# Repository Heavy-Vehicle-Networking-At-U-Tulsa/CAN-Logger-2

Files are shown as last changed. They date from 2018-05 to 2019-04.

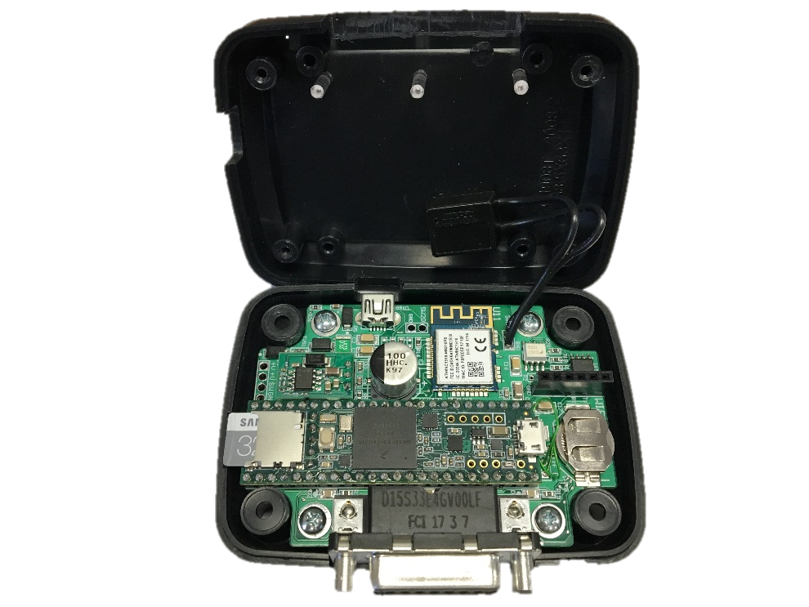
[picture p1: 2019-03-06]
docs/Picture of CAN Logger 2.png

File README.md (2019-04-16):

# CAN-Logger-2
Source code and documentation for the CAN Logger 2

## Purpose: 
Use as an educational tool to interface with CAN, including dual CAN channels, MCP2515 third CAN, Single Wire CAN, LIN, J1708, WIFI, LEDs, and pushed button

## Submodules
The CAN Logger 2 depends on the following libraries:
  * FlexCAN_Library forked from Collin80: https://github.com/Heavy-Vehicle-Networking-At-U-Tulsa/FlexCAN_Library
  * MCP_CAN_lib forked from Cory Fowler: https://github.com/Heavy-Vehicle-Networking-At-U-Tulsa/MCP_CAN_lib
  * Arduino's Wifi101 library: https://github.com/arduino-libraries/WiFi101
  
To use these submodules, you have to open a Git Bash command perform an update. Assuming Windows with Git installed:

```cd Documents/GitHub/CAN-Logger-2/``` (or equivalent directory for this repository.

```git submodule update --init```

### Installing Arduino Libraries
In Arduino 1.8.5, Click Sketch -> Include Library -> Add .Zip Library

Navigate to the submodule directory within this repository and select the name of the directory. A message should show up in Arduino saying "Library added to your libraries."

If there is an error in importing the libraries, you may need to remove exising libraries (see below).

#### Removing Existing Libraries 
Once the modules are updated, you need to make them available to your Arduino environment. Again, assuming Windows, open Git Bash.

```cd ~/Documents/Arduino/libraries```

``` rm -r FlexCAN_Library``` or other libraries.

You may also need to remove the pre-installed FlexCAN_Library:

```cd C:\Program Files (x86)\Arduino\hardware\teensy\avr\libraries```

``` rm -r FlexCAN_Library``` or other libraries.

## Usage
The following charts show the functionality of the CAN Logger 2 units. These charts are available as a pdf and include program flow and data structures.

[NMFTA TU CAN Logger 2 Diagrams](docs/NMFTA_TU_CAN_Logger_2%20Block%20Diagrams.pdf)

## Logger Device Test Programs
The test programs are in the `tests` directory

### `Test_LED_with_Button` 
Test code used to turn on three LEDs by pushing the button. The sketch makes use of the follwing defines based on the circuit design:

```
#define GREEN_LED_PIN 6
#define RED_LED_PIN 14
#define YELLOW_LED_PIN 5
#define button 21
```

### `Test_CAN0_and_CAN1`
Test codes used to send/receive CAN message periodically on both channels CAN0 and CAN1 using FLEX CAN library. 

This makes use of the following defines for the Silent Pins on the transceivers:
```
#define SILENT_0 39
#define SILENT_1 38
#define SILENT_2 37
```
Pull the silent pins low for transmission.

### `Test_MCP2515_Receive and Test_MCP2515_Send`
Test code used to send/receive CAN message periodically through third CAN channel using MCP library. 

## Utilities
There are a few utilities useful when using the CAN Logger 2.

### Flood the BUS with button
Test code to send messages with top priority messages at maximum speed to flood the bus as the button is pressed.

## WiFi
The CAN Logger 2 has a the ATWINC1500 Wifi module. By default, this module is disabled (i.e. not wired correctly.) If the wiring is fixed, then the Wifi can be used. 
Test codes used to wireless communicate through WiFi between the WiFi chip on the logger with one another. The WiFi 101 library can be accessed here: https://github.com/adafruit/Adafruit_WINC1500. To correctly use the WiFi chip on the Logger 2, SPI1 has to be selected by: Adafruit_WINC1500-master>src>bus_wrapper>source>nm_bus_wrapper_samd221.cpp, change line 54 to #define WINC1501_SPI SPI1.

## Acknowledgements 
This material is based upon work supported by the National Science Foundation under Grant No. 1715409.

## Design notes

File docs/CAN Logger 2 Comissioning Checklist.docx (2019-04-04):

Commissioning the CAN Logger 2

- Customer Name:_________________________________________________

Assembly:

- PCB board is screwed in the enclosure
- Push button is soldered in SW20 and attached to enclosure top half
- Jumper wire between R20 and RAW in P1 for optically isolated inputs
- Insert micro SD card
- Insert 3V coin battery

WiFi Enable / Disable (Circle one)

- WiFi enable - Jumper wire between Teensy pin 21 and WiFi chip RST pin
- WiFi disable - No jumper wire
- Screw enclosure top and bottom together
- Add D-Sub 15 to green 9-pin cable

Testing:

- Update firmware on Logger 2. Record the git commit hash: ________________

https://github.com/Heavy-Vehicle-Networking-At-U-Tulsa/CAN-Logger-2/tree/master/CAN_Logger_with_Autobaud_and_Requests

- Open Serial Monitor and Record the Logger 2 Date:_______________________
- Program and Label Enclosure Bottom with Serial number:__________________
- Enter the command FORMAT to clear the SD CARD.
- Enter the command COUNT to reset the file counter.
- Enter the command DF and record the free space on the SD Card: ___________
- Connect to live monitored CAN BUS (250k) with can0, can1, and can2 channels.
- Enter the command STREAM ON and see all three channels scroll in the first column.
- Double Click the Push Button and confirm 3 LEDs illuminate and a new file opens.
- Enter the Command LS A and confirm two files were created on the SD card.
- Press pushbutton once and confirm request messages are sent.
- Parse CAN Log to find ECM component ID. Record ID_______________________
- Unplug the CAN Logger USB first, then the DSUB cable while recording.
- Reconnect to live monitored CAN BUS (500k) with can0, can1, channels and J1708.
- Enter the command baudRate and confirm the new bitrates were recorded.
- Type the Command LS A and confirm the third file exists and after the power loss.
- Enter the command STREAM ON and confirm J1708 is not interfering can2
- Scan and record this checklist
- Insert the device, D-Sub cable and checklist in anti-static bag

Notes:

Selling and Shipping a Forensic Link Adapter with TruckCRYPT.docx Page 2 of 2

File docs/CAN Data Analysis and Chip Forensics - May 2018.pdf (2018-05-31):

Electronic Control Unit and CAN Data Analysis

Jeremy Daily, Ph.D., P.E.
jeremy-daily@utulsa.edu
Associate Professor of Mechanical Engineering

Overview

1. CAN Logger (version 2) Update
2. Network and Application Based CAN Capture
3. Chip Level Capture
4. Analysis, Decoding and Presenting the Data

Some contents were originally published in SAE 2015-01-1450

Logging Heavy Vehicle Network Traffic

■ Capture as much raw operational CAN data from heavy vehicles as possible. ■ Store Heavy Vehicle Network Messages on SD Card
■ Unique opportunity for a unique data set
■ Data is sanitized and stored by NMFTA
■ Implementation
■ CAN Logger V2
■ Faster
■ More Networks
■ Better Enclosure
■ Open Source
■ Functional Tool

NMFTA CAN Logger V2

■ Logging Interfaces
■ 3 – High Speed CAN
■ 1 – Single Wire CAN
■ 1 – LIN
■ 1 – J1708
■ External Connectivity
■ Vehicle Network Interface
■ Wi-Fi
■ USB
■ 180 MHz 32-bit ARM Cortex M4F ■ Button for marking data
■ Three LEDs

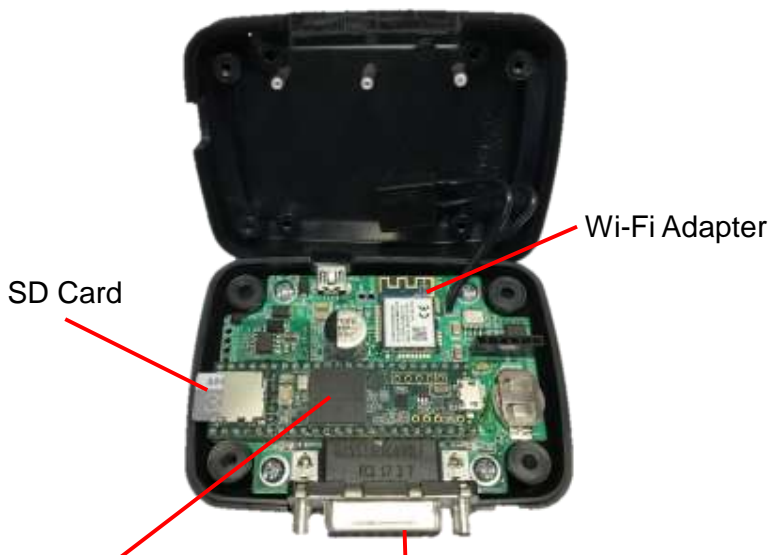
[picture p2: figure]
SD Card; Wi-Fi Adapter

Teensy 3.6 Arduino
Compatible
Development Board

Vehicle Network
Interface

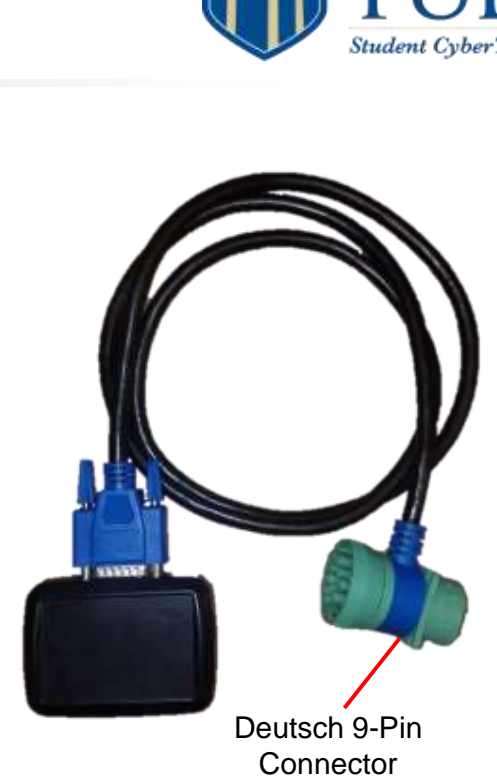
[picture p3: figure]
Deutsch 9-Pin Connector

Why is it Useful?

■ Vehicle Network Interface
■ D-sub 15 to Deutsch 9-Pin
■ Deutsch 9-Pin is a Heavy Vehicle Standard
■ Uses Diagnostic Port for Logging
■ Easy Data Collection of Heavy Vehicle Networks ■ Common Learning Platform
■ Statistical Differences Between
■ Normal Drive
■ Normal Drive with Attacks
■ 100% Open Source

Testing: Two at a Time

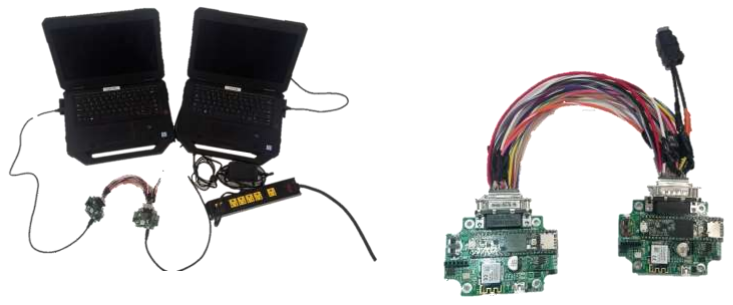
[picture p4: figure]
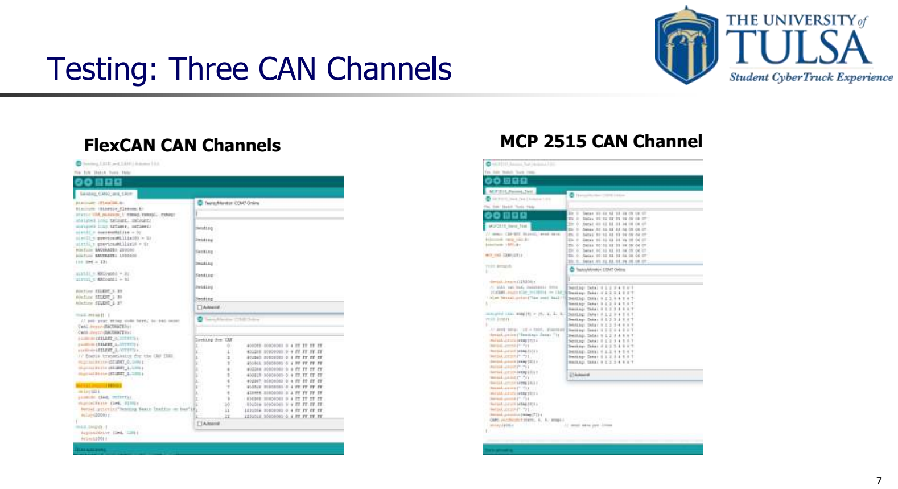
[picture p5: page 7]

Testing: Three CAN Channels

FlexCAN CAN Channels | MCP 2515 CAN Channel

Testing: Other Vehicle Networks

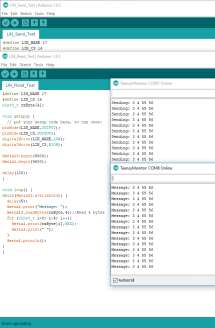
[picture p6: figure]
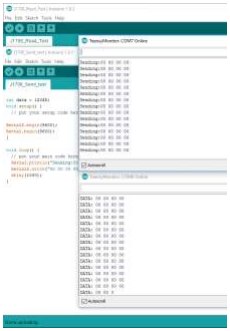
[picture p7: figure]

LIN | J1708

Testing: SD Card Writing Speed

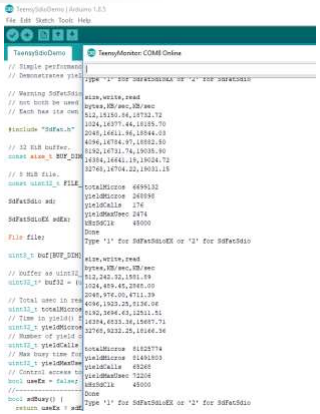
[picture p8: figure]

■ Write Time
■ 512 Bytes ≈ 240µS
■ Suitable For:
■ Full Bus Loads
■ Multiple CAN Channels
■ Logging Secondary Communications

LOGGING DATA WITH RP1210 APPLICATIONS

Alternative Method of Acquiring Data:

The TU-RP1210 Application

■ A Graphical User Interface to log, decode, and display data in with an open framework.
■ Python, Qt, and ctypes
■ Uses DLLs from RP1210 Vendors

`

J1939 Parameter Group Numbers

- Decoding
- Counting
- Timing

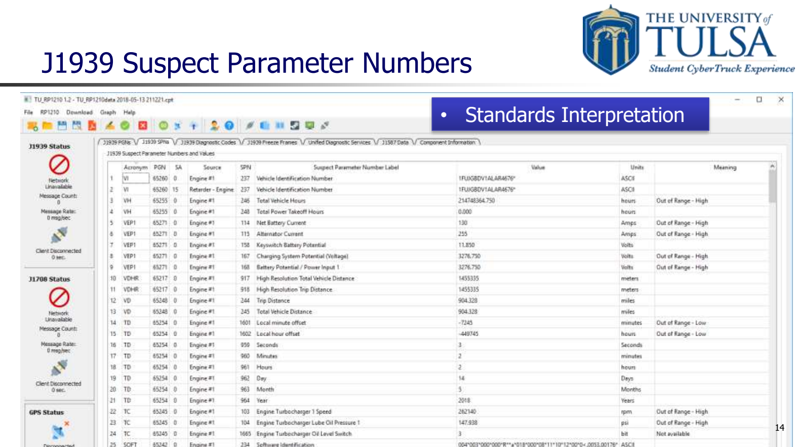
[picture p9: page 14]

J1939 Suspect Parameter Numbers

- Standards Interpretation

J1939 Diagnostic Codes (DM1 and DM2)

ISO-14229:
Unified Diagnostic Services (UDS)

Component Information Summary

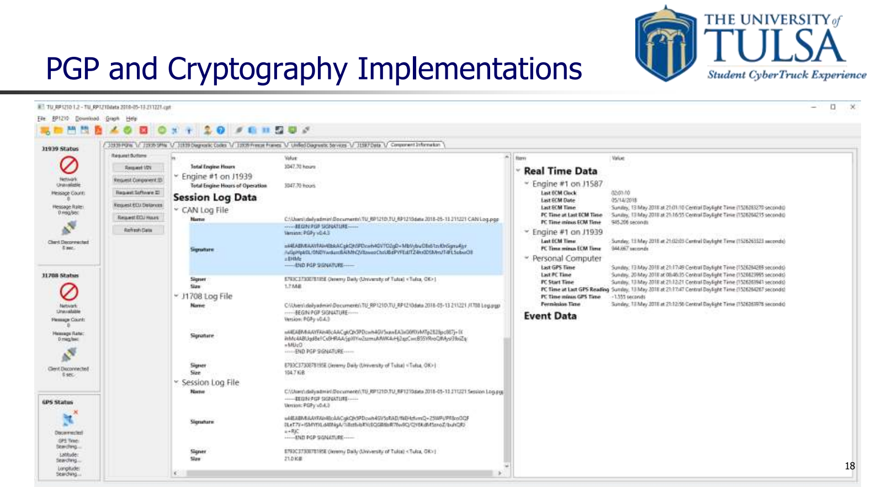
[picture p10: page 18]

PGP and Cryptography Implementations

Open Source Framework

■ Available on PyPi
■ Uses PyQT5
■ REST for Web Applications

■ Teaching Tool
■ RP1210 Function Validation ■ Data Analysis

Data Storage

■ JSON file for decoded data
■ CSV log files for Vehicle Networks
■ PDF Report generator using Reportlab
■ Pretty Good Privacy (PGP) implementation for file signing

CAN WE OBTAIN MEMORY
CONTENTS THOUGH JTAG PORTS?

Forget about the network…

A Journey Into Chip Forensics

Duy Van

Undergraduate in Mechanical Engineering duy-van@utulsa.edu

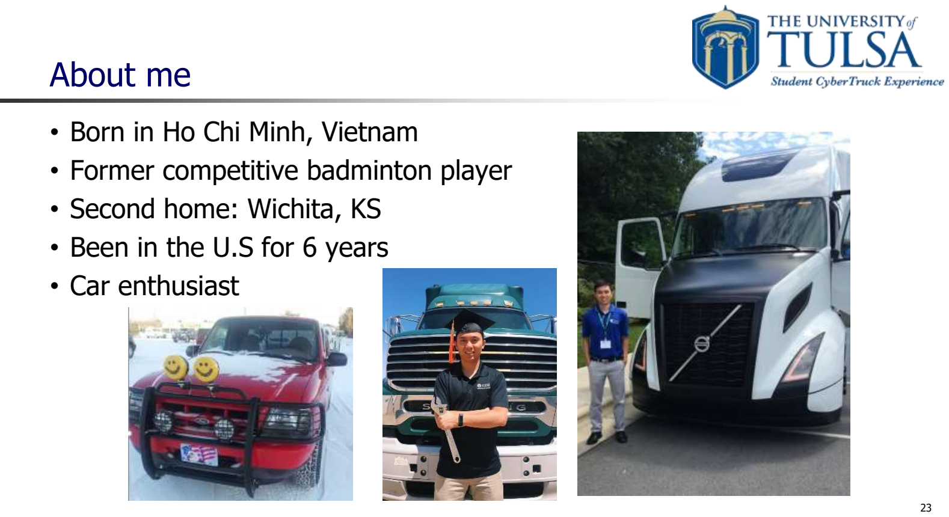
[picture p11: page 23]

About me

- Born in Ho Chi Minh, Vietnam
- Former competitive badminton player
- Second home: Wichita, KS
- Been in the U.S for 6 years
- Car enthusiast

Cyber Security Minor at UTULSA

Additional Courses

■ Intro to Cyber Security
■ Computer Forensics
■ Computer Security
■ Secure Electronic Commerce

Relevant Projects

■ Password cracking
■ Acquire and analyze computer’s hard drive
■ Writing AES encryption from scratch using C
■ Attack a virtual website with XSS, SQL injection, directory traversal, etc. and fix the vulnerabilities by changing source codes.

This is on top of a
Mechanical Engineering
degree…

Purposes and Procedures

■ Explore data patterns between RP1210 traffic logs and raw memory
■ Download Dataplate and Sudden Deceleration using Cummins PowerSpec
■ Collect raw data from FLASH and EEPROM through JTAG ■ Compare the data and decode raw binary

ECM Used

Cummins ECU CM870

DOWNLOADING DATA FROM
POWERSPEC

Tools

Inline 7
(Diagnostic Adapter)

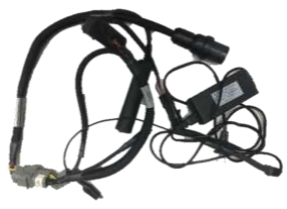
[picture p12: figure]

Connecting
Harness

Setup

Software

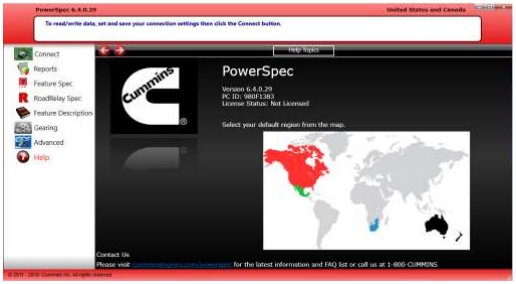
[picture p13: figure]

Cummins PowerSpec

Downloading Data

Dataplate | Sudden Deceleration

COLLECTING RAW DATA FROM K-TAG

Tool

AlienTech KTAG Master Kit from a European Chip Tuning shop

Software Interaction

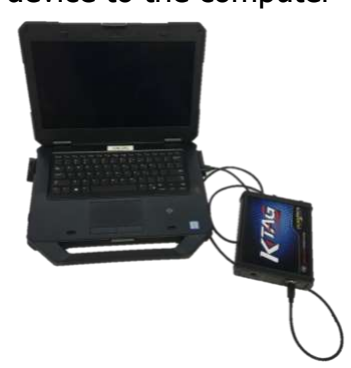
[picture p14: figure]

■ Connect KTAG device to the computer

Software Interaction

■ Run the K-Suite software from AlienTech

Software Interaction

■ Select purchased version (KTAG in this case)

Software Interaction

■ Purchased chip protocols will be in black font color and can be selected.
■ Vehicle types can also be selected if chip protocol is unknown at this moment.

Software Interaction

■ If chip protocol is known, choose the protocol

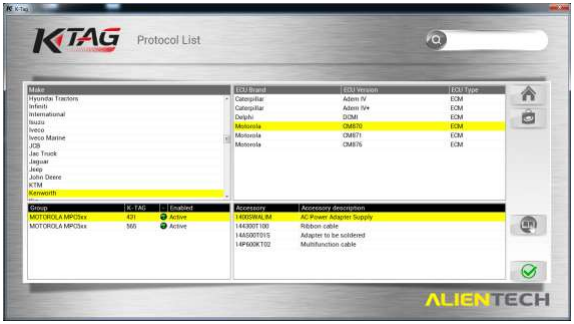
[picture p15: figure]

Software Interaction

■ If vehicle type is known, choose the vehicle

Software Interaction

■ Search option is also available

Software Interaction

■ After choosing the correct ECU, click on the book mark icon for wiring instruction

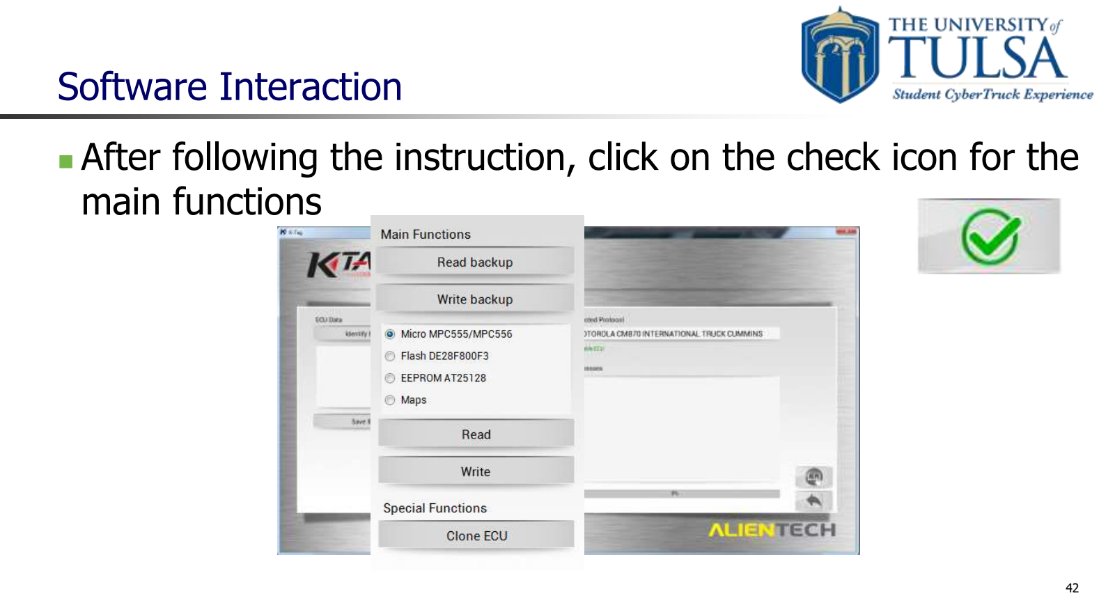
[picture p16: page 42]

Software Interaction

■ After following the instruction, click on the check icon for the main functions

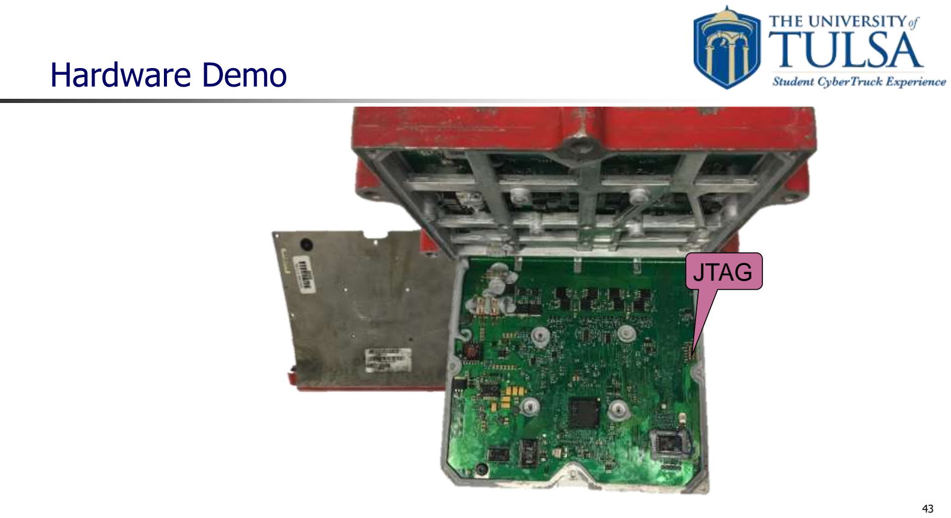
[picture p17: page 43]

Hardware Demo

JTAG

Hardware Interaction

■ Follow the instruction on the software, solder the port and

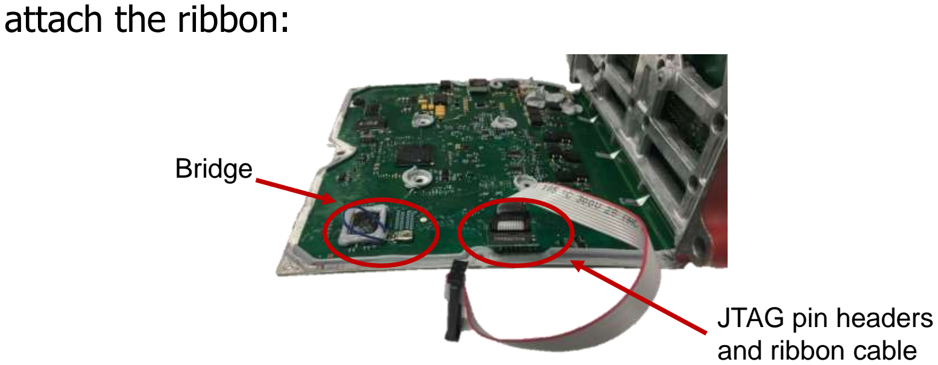
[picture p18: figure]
attach the ribbon:; Bridge; JTAG pin headers and ribbon cable

Hardware Interaction

■ Attach the D-sub cable to the ECU connector ■ Power
■ Ignition

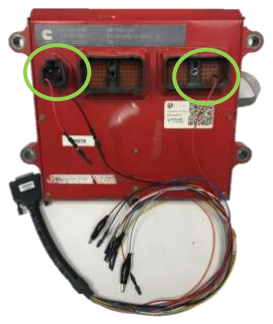
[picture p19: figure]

Setup

■ Connect the KTAG to the ECU and the computer

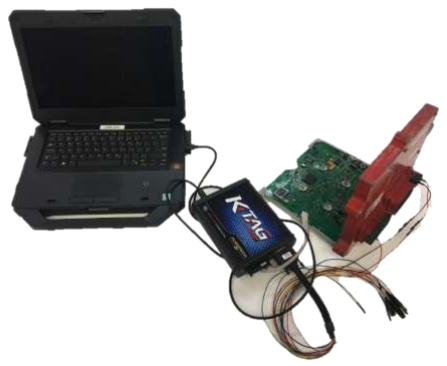
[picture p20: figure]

Retrieving Data

■ Select the desired function in the software ■ In this case, select Maps and Read function

Retrieving Data

■ Wait for the process to complete

Retrieving Data

■ Save the files separately

Data Analysis

■ Use Hexinator to open the output MPC file

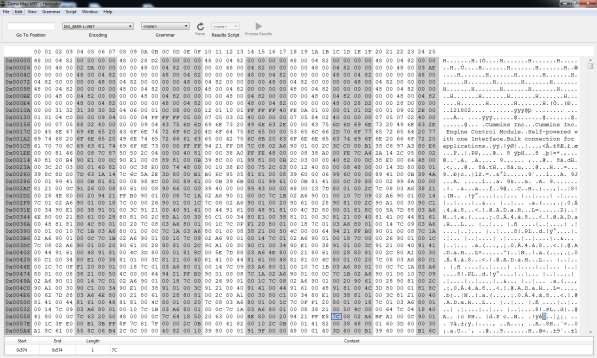
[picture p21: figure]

Data Analysis

■ Some meaningful strings are present indicating that the data is not encrypted

Data Analysis

■ Closer look between PowerSpec vs EEPROM

Data Analysis

■ For CM870, EEPROM carries data plate information via ASCII

Data Analysis

■ Flash file from KTAG

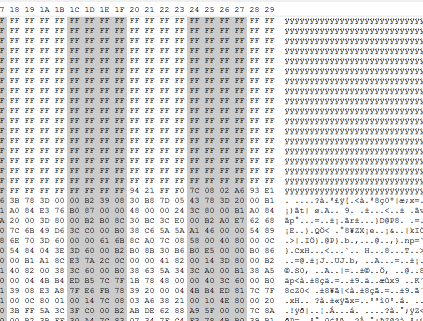
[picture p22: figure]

Data Analysis

■ Flash data can also be retrieved using individual chip reader

Xeltek Superpro 6000

Data Analysis ■ Flash chip data should

carry Sudden Decel
Information (vehicle
speed, engine RPM, etc.)
■ Not easy to find the data location

Data Analysis

One approach:
■ Vehicle speed for
Record 1 has 150 mph
for the first 60s

Data Analysis

■ Converting the actual vehicle speed into data format using J-1939-71

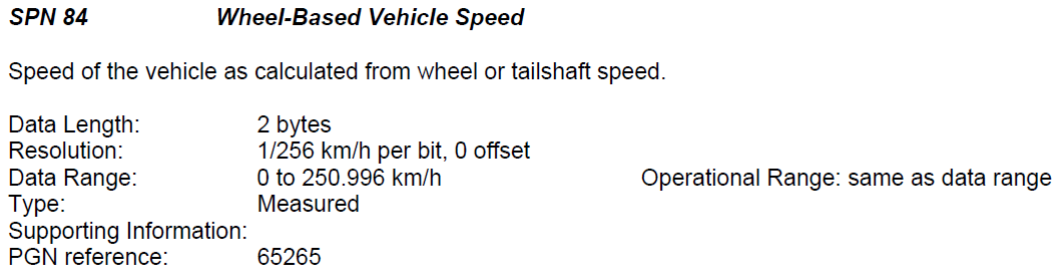
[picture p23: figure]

Data Analysis

■ Convert 150 mph to km/h: 241.4 km/h ■ Convert 241.4 km/h to bit:
241.4 km/h x 256 bit/km/h = 64798.4 bit ■ Convert 64798.4 to Hex: F1 66
■ Look for repeating F1 66 pattern in the FLASH memory

NO PATTERN! WHAT NOW?!

Data Analysis

■ Convert 150 mph to data format without converting to km/h ■ Convert 150 to bit:
150 *256 = 38,400
■ Convert 38,400 to Hex: 96 00

Data Analysis

■ WOOHOO! We got something

Data Analysis

■ But is it the vehicle speed log?
■ Tracing the speed along to compare with the report. The 2-byte is 12 bytes apart

Data Analysis

■ Convert 58 8A to actual vehicle speed number: ■ 58 8A to Decimal: 22,666
■ Convert 22,666 to actual number:
22,666 / 256 = 88.54 mph

Data Analysis

Data Analysis

■ What about engine RPM, load, throttle, etc.? ■ Take a look at 14-byte block in Record 2 data

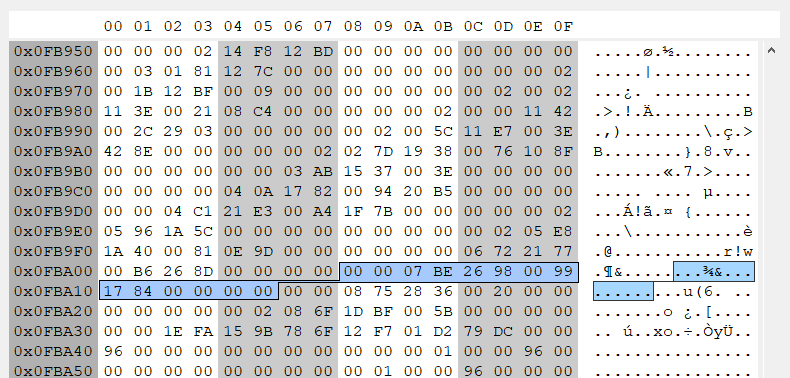
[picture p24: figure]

Data Analysis

Data Analysis

■ Comparing memory data with CAN traffic from PowerSpec

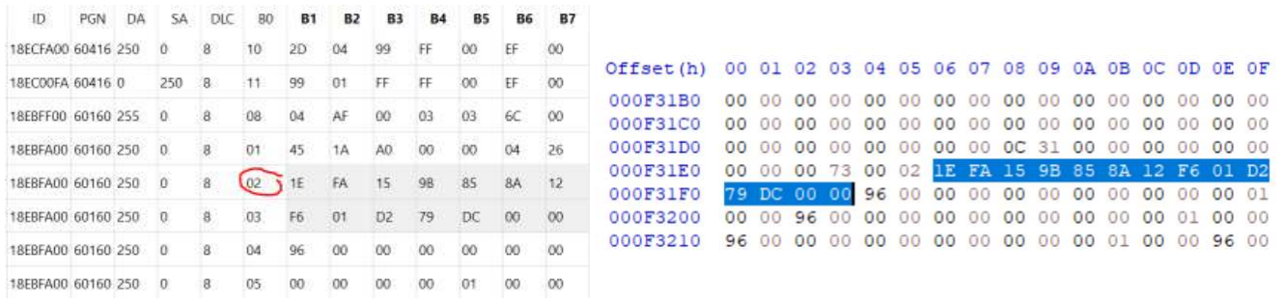
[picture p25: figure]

■ The results show CAN traffic delivers the exact data from
the memory with 7 bytes for every package | 68
CAN Traffic from PowerSpec | FLASH Memory

Next Steps

■ Write a script to parse through raw data to obtain sudden deceleration information
■ Explore the specific pattern to find the location of sudden decel for different ECUs
■ Write a Hexinator Grammar to automatically analyze binary data ■ Correlate network traffic with memory contents
■ Publish SAE papers
■ Maybe: patch memory to subvert normal functions

Additional Goals ■ Analyze multiple ECMs ■ Recover data from wrecked

ECMs
■ Recover data without setting fault codes
■ Virtual Chip Swap ■ Deep Dive: Build our own

KTAG tool

Thank you! | 70

Conclusions ■ Three ways of collecting data ■ CAN Data Loggers ■ Version 1 produced over 4000 hours ■ Version 2 has more tool-like features ■ RP1210 Application Logging ■ Fuzzing and Requesting ■ Eavesdropping ■ Memory Interrogation ■ Data Analysis ■ Counts and timing ■ Standards based meaning ■ Pattern matching

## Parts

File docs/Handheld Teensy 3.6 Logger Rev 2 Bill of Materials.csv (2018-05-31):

Comment | Description | Designator | Footprint | LibRef | Manufacturer 1 | Manufacturer Part Number 1 | Quantity | Supplier 1 | Supplier Order Qty 1 | Supplier Part Number 1
47 | ±1% 0.1W, 1/10W Chip Resistor 0603 (1608 Metric) Automotive AEC-Q200, High Voltage Thick Film | R5, R6, R24, R25 | 603 | Chip Resistor | Rohm | KTR03EZPF47R0 | 4 | Digi-Key | 4 | RHM47AYCT-ND
100k | ±1% 0.1W, 1/10W Chip Resistor 0603 (1608 Metric) Automotive AEC-Q200, High Voltage Thick Film | R8, R9, R11, R12, R13, R16, R17, R23, R26 | 603 | Chip Resistor | Rohm | KTR03EZPF1003 | 9 | Digi-Key | 9 | RHM100KAYCT-ND
4.7k | ±1% 0.1W, 1/10W Chip Resistor 0603 (1608 Metric) Automotive AEC-Q200, High Voltage Thick Film | R1, R4, R7, R10, R21, R22 | 603 | Chip Resistor | Rohm | KTR03EZPF4701 | 6 | Digi-Key | 6 | RHM4.7KAYCT-ND
1uf | 1µF ±20% 50V Ceramic Capacitor X5R 0603 (1608 Metric) | C10 | 603 | Cap | Murata | GRT188R61H105ME13D | 1 | Digi-Key | 1 | 490-12331-1-ND
10uF | 10µF ±20% 25V Ceramic Capacitor X5R 0603 (1608 Metric) | C4 | 603 | Cap | Murata | GRT188R61E106ME13D | 1 | Digi-Key | 1 | 490-12323-1-ND
10uF | 10µF ±20% 50V Ceramic Capacitor X5R 1206 (3216 Metric) | C5, C7 | 1206 | Cap | Murata | GRT31CR61H106ME01L | 2 | Digi-Key | 2 | 490-12457-1-ND
22uF | 22µF ±20% 25V Ceramic Capacitor X5R 1206 (3216 Metric) | C2, C12, C16, C17 | 1206 | Cap | Murata | GRT31CR61E226ME01L | 4 | Digi-Key | 4 | 490-12451-1-ND
330 | 330 Ohms ±1% 0.1W, 1/10W Chip Resistor 0603 (1608 Metric) Automotive AEC-Q200, High Voltage Thick Film | R2, R3, R18, R19, R20 | 603 | Chip Resistor | Rohm | KTR03EZPF3300 | 5 | Digi-Key | 5 | RHM330AYCT-ND
Varistor 26V | 34.5V 80A Varistor 1 Circuit Surface Mount 0805 (2012 Metric) | TVS1 | Transfeed | Transfeed | Kyocera AVX | V2AF126C600Y2EDP | 1 | Digi-Key | 1 | 478-10038-1-ND
OKI-78SR | 5V DC/DC Converter (7805 replacement) | U1 | OKI-78SR | 7805 | Murata | OKI-78SR-5/1.5-W36H-C | 1 | Digi-Key | 1 | 811-2692-ND
100uF | Aluminum Electrolytic Capacitors Radial, Can - SMD 5000 Hrs @ 105°C | C3 | Elec. Cap - G | Tantalum Cap_1 | Panasonic ECG | EEE-HC1H101P | 1 | Digi-Key | 1 | P19732CT-ND
ATECC508A | Authentication Chip IC Networking and Communications 8-SOIC | U15 | SOIC-8 | ATECC508A | Microchip / Atmel | ATECC508A-SSHDA-T | 1 | Digi-Key | 1 | ATECC508A-SSHDA-TCT-ND
MCP2515-E/ML | CAN Controller CAN 2.0 SPI Interface 20-QFN (4x4) | U14 | QFN-ML20_M | MCP2515-E/ML | Microchip | MCP2515-E/ML | 1 | Digi-Key | 1 | MCP2515-E/ML-ND
0.1uF | CAP CER 0.1UF 50V X7R 0603, CAP CER 0.1UF 50V 10% X7R 0603, CAP CER 0.1UF 50V 10% X7R 0603, CAP CER 0.1UF 50V X7R 0603, CAP CER 0.1UF 50V X7R 0603, CAP CER 0.1UF 50V 10% X7R 0603 | C1, C6, C8, C9, C11, C15 | 603 | Cap | Murata | GRM188R71H104KA93D | 6 | Digi-Key | 6 | 490-1519-1-ND
18pF | CAP CER 18PF 50V 5% NP0 0603 | C13, C14 | 603 | Cap | KEMET | C0603C180J5GAC-TU | 2 | Digi-Key | 2 | 399-1052-1-ND
Wifi | CONN HEADER FEMALE 6POS .1 GOLD" | WIFI | HDR1X6 | Header 6 | Sullins | PPPC061LFBN-RC | 1 | Digi-Key | 1 | S7039-ND
16MHz | CRYSTAL 16MHZ 18PF SMD | X1 | XTAL 2 pad | Crystal Oscillator | TXC | 7A-16.000MAAJ-T | 1 | Digi-Key | 1 | 887-1086-1-ND
ACURA107-HF | Diode Schottky 1000V 1A Surface Mount DO-214AC (SMA) | D3, D5 | SMA with A and K | Schottky Diode | Comchip | ACURA107-HF | 2 | Digi-Key | 1 | 641-1884-1-ND
SN75HVD08DR | IC RS485 TXRX 3/5V 8-SOIC | U4 | SOIC-SN8_N | SN75HVD12D (3.3v RS485) | Texas Instruments | SN75HVD08DR | 1 | Digi-Key | 1 | 296-37893-1-ND
74AHCT1G14 | IC SCHMIT-TRIGG INV GATE SOT353 | U3 | SOT-353 | 74AHCT1G14 Inverter | Diodes | 74AHCT1G14SE-7 | 1 | Digi-Key | 1 | 74AHCT1G14SE-7DICT-ND
ADG1634BCPZ-REEL7 | IC SWITCH QUAD SPDT 20LFCSP | U6 | ADI-CP-20-4_N | ADG1634BCPZ-REEL7 | Analog Devices | ADG1634BCPZ-REEL7 | 1 | Digi-Key | 1 | ADG1634BCPZ-REEL7CT-ND
Green | LED GREEN DIFFUSED 0805 SMD | D1 | 0805 Polarized | LED - SMD | Osram Opto | LGR971-KN-1-0-20-R18 | 1 | Digi-Key | 1 | 475-1410-1-ND
Red | LED RED DIFFUSED 0805 SMD | D2 | 0805 Polarized | LED - SMD | Osram Opto | LSR976-NR-1 | 1 | Digi-Key | 1 | 475-1278-1-ND
Yellow | LED YELLOW DIFFUSED 0805 SMD | D4 | 0805 Polarized | LED - SMD | Osram Opto | Q62702P5177 | 1 | Digi-Key | 1 | 475-2560-1-ND
MCP2003A-E/SN | LIN J2602 Transceiver, 8-Pin SOIC, Extended Temperature, Tape and Reel | U7 | SOIC-SN8_N | MCP2003AT-E/SN | Microchip | MCP2003A-E/SN | 1 | Digi-Key | 1 | MCP2003A-E/SN-ND
NCP1117LPST33 | Linear Voltage Regulator IC Positive Fixed Output 3.3V 1A SOT-223 | U13 | SOT-223 | NCP1117 2.5V | ON Semiconductor | NCP1117LPST33T3G | 1 | Digi-Key | 1 | NCP1117LPST33T3GOSCT-ND
CR1225 | Lithium Battery Non-Rechargeable (Primary) 3V Coin, 12.5mm | Batt1 | Battery Clip - CR1225 | CR2032 Battery Holder | Linx | BAT-HLD-012-SMT | 1 | Digi-Key | 1 | BAT-HLD-012-SMT-ND
MCP2558 | Microchip CAN FD Transceiver with Silent Mode | U5, U8, U9 | TDFN | MCP2558FD | Microchip |  | 3 | Arrow | 3 | MCP2558FDT-H/MNY
MOCD207R2M | Optoisolator Transistor Output 2500Vrms 2 Channel 8-SO Tall | U12 | SOIC-8 | Optoisolator - Dual | Fairchild Semiconductor | MOCD207R2-M | 1 | Digi-Key | 1 | MOCD207R2MCT-ND
PTC RESTTBLE 0.75A | PTC RESTTBLE 0.75A 33V CHIP 1812 | PTC1 | 1812 | PTC | Bel | 0ZCG0075BF2B | 1 | Digi-Key | 1 | 507-1765-1-ND
Vehicle Interface Cable Connector | Receptacle Assembly, 15 Position, Right Angle | J1 | DSUB1.385-2H15 | D Connector 15 | Amphenol FCI | D15S33E4GV00LF | 1 | Digi-Key | 1 | 609-1498-ND
NCV7356D1R2G | Single Wire CAN Transceiver, 5 to 27 V, 8-Pin SOIC, Pb-Free, Tube | U2 | ONSC-SOIC-8-751-07_V | NCV7356D1G | ON Semiconductor | NCV7356D1R2G | 1 | Digi-Key | 1 | NCV7356D1R2GOSCT-ND
ATML-ATWINC1500-MR210PA-28 | SMARTCONNECT ATWINC1500B-MU-T MO | U11 | ATML-ATWINC1500-MR210PA-28_V | ATML-ATWINC1500-MR210PA-28 | Microchip | ATWINC1510-MR210PB1140 | 1 | Digi-Key | 1 | ATWINC1510-MR210PB1140-ND
SMA6J | TVS DIODE 20VWM 36.8VC SMA | Z1 | SMA | Zener - Bidirectional | MCC | SMA6J24CA-TP | 1 | Digi-Key | 1 | SMA6J24CA-TPMSCT-ND
UX60SC-MB-5S8 | USB - mini B USB 2.0 Receptacle Connector 5 Position Surface Mount, Right Angle; Through Hole | USB1 | USB Mini UX60S | USB-Rugged | Hirose | UX60SC-MB-5S8 | 1 | Digi-Key | 1 | H11589CT-ND

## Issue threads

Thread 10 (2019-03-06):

Serial Command

duyvan1995, 2019-03-06:
Command start with brand_name on line 1031 just closes the current file.
Command HEX and BIN print the latest log file but are they supposed to save them on PC? If yes then location to save? @jeremy-daily

jeremydaily, 2019-03-31:
These commands are to stream the data in the specified format for storage with another computer.

Closed 2019-03-31.

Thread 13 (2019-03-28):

CAN1 is not working when plug in

duyvan1995, 2019-03-28:
CAN1 only works if the Logger stops the current file after plugging in and starts a new log file

jeremydaily, 2019-03-31:
Is this an autobaud issue? Can you duplicate this issue and provide more description of the setup @duyvan1995?

duyvan1995, 2019-03-31:
The issue is resolved with the latest code

duyvan1995, 2019-04-07:
Just saw the same issue: if the is rebooted (was off then plugged in the BUS to start recording), the streaming and recording will only see channel 0 until I typed "stop" in the serial command and the channel 1 started showing up. Double click the button won't fix the issue

duyvan1995, 2019-04-07:
The issue occurs when plugging in the the ECM and SSS2 only, I plugged in a TruckCape and do a cangen on can1 and the issue is gone. Not sure what happened

jeremy-daily, 2019-04-08:
Can we close this again?

Closed 2019-04-08.

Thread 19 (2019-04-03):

Request component ID

duyvan1995, 2019-04-03:
Does not see request messages sent from the device

duyvan1995, 2019-04-04:
Fixed with new source code

Closed 2019-04-04.

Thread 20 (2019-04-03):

Listen Only Mode

duyvan1995, 2019-04-03:
Device does not act as a node even if listen only mode is set to false

jeremy-daily, 2019-04-08:
Was this was fixed with the updated flexcan library?

duyvan1995, 2019-04-08:
No, still did not see messages generated from a single CAN Logger, need to plug in a SSS2 to see those messages

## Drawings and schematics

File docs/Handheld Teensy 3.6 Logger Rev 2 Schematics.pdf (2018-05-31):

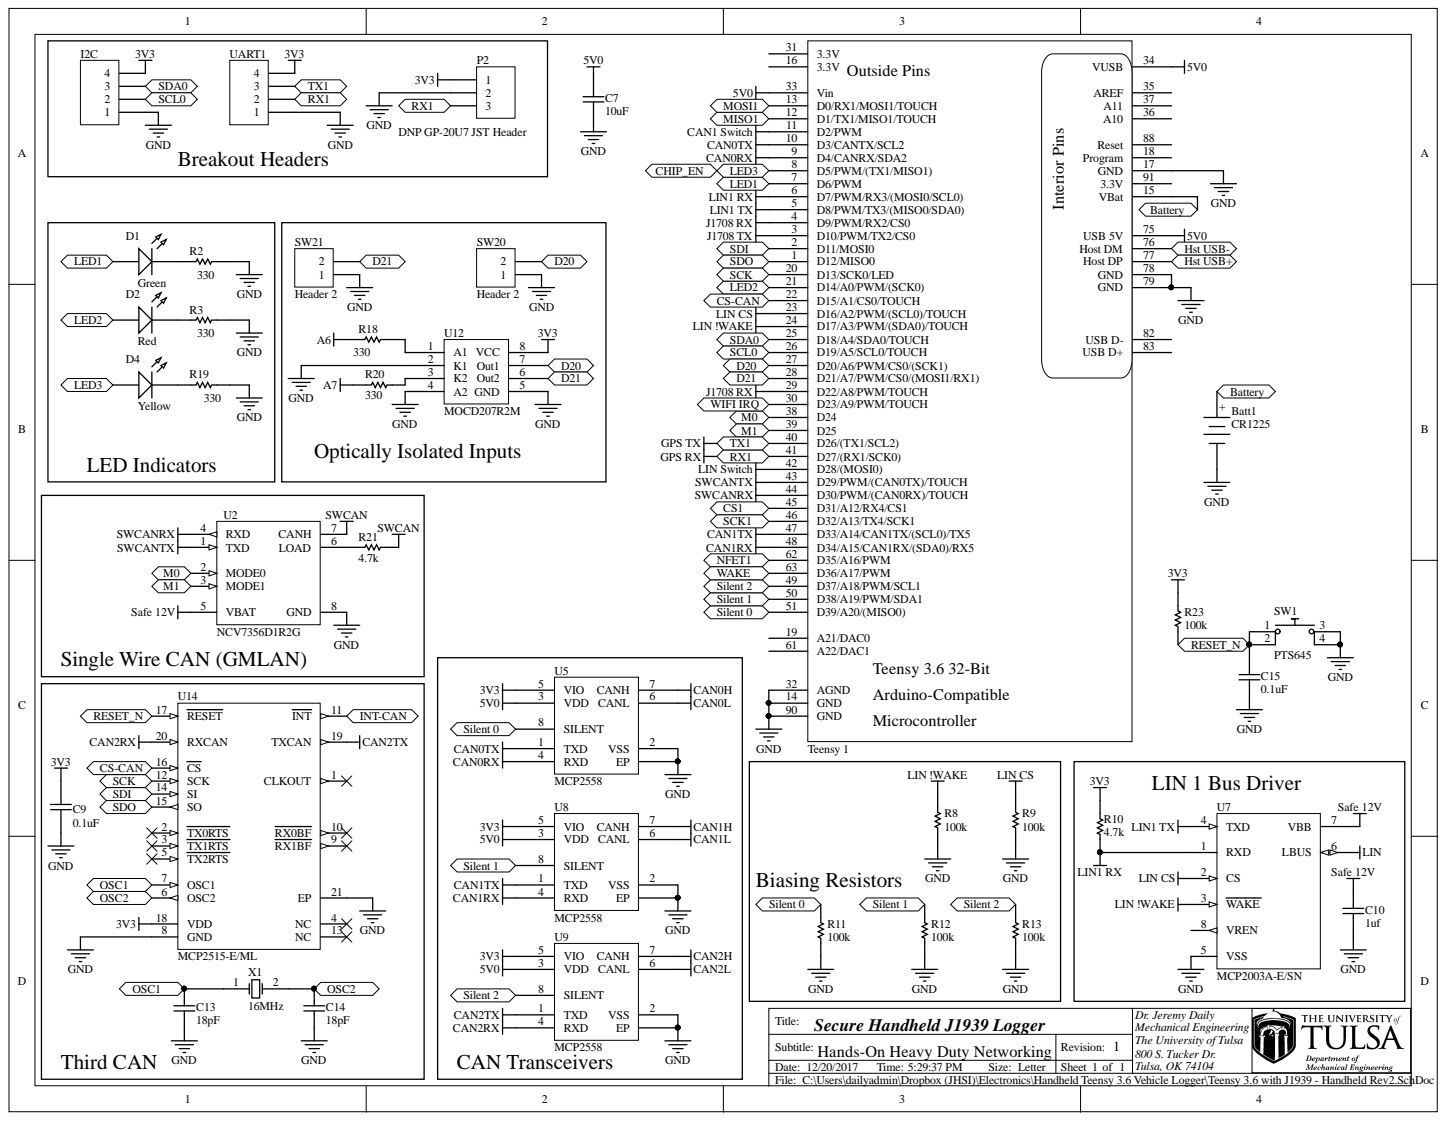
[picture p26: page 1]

GND
DNP GP-20U7 JST Header

Single Wire CAN (GMLAN)

Title: Secure Handheld J1939 Logger | Dr. Jeremy Daily Mechanical Engineering The University of Tulsa 800 S. Tucker Dr. Tulsa, OK 74104

Hands-On Heavy Duty Networking Subtitle: | 1 Revision:

Date: 12/20/2017 Time: 5:29:37 PM Size: Letter | Sheet of

C:\Users\dailyadmin\Dropbox (JHSI)\Electronics\Handheld Teensy 3.6 Vehicle Logger\Teensy 3.6 with J1939 - Handheld Rev2.SchDoc

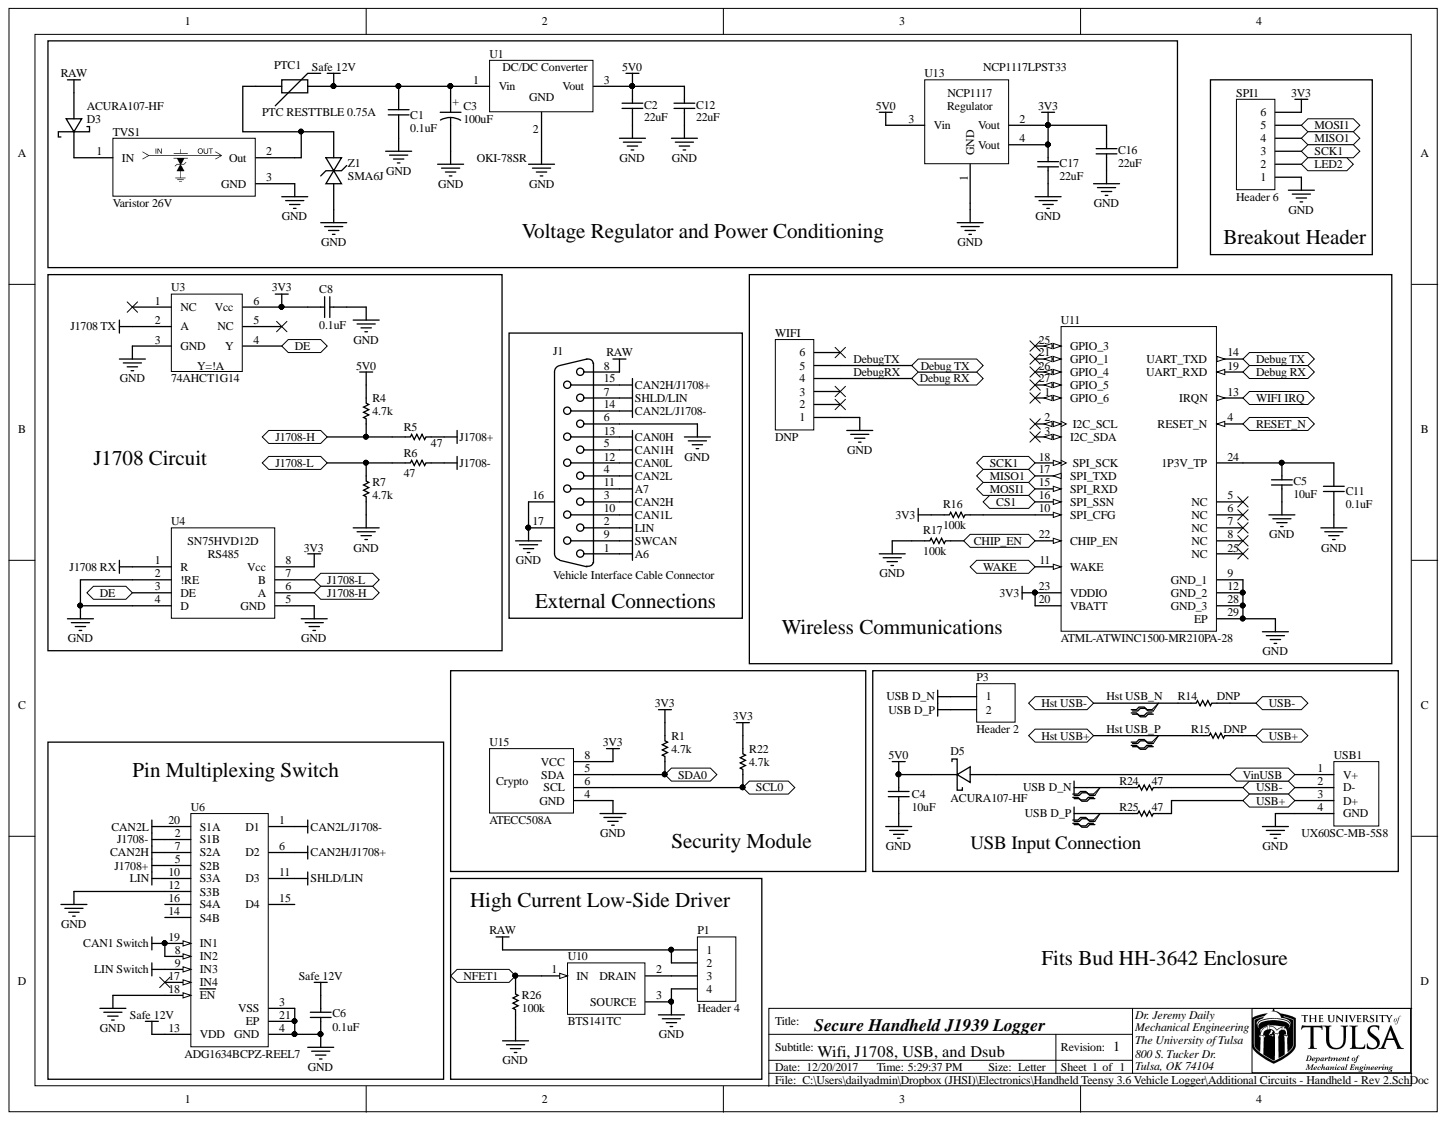
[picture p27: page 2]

Voltage Regulator and Power Conditioning

Vehicle Interface Cable Connector
External Connections

High Current Low-Side Driver

U10
IN 1 DRAIN | 2

Fits Bud HH-3642 Enclosure

Dr. Jeremy Daily
Mechanical Engineering
The University of Tulsa
800 S. Tucker Dr.
Tulsa, OK 74104

Subtitle:
C:\Users\dailyadmin\Dropbox (JHSI)\Electronics\Handheld Teensy 3.6 Vehicle Logger\Additional Circuits - Handheld - Rev 2.SchDoc

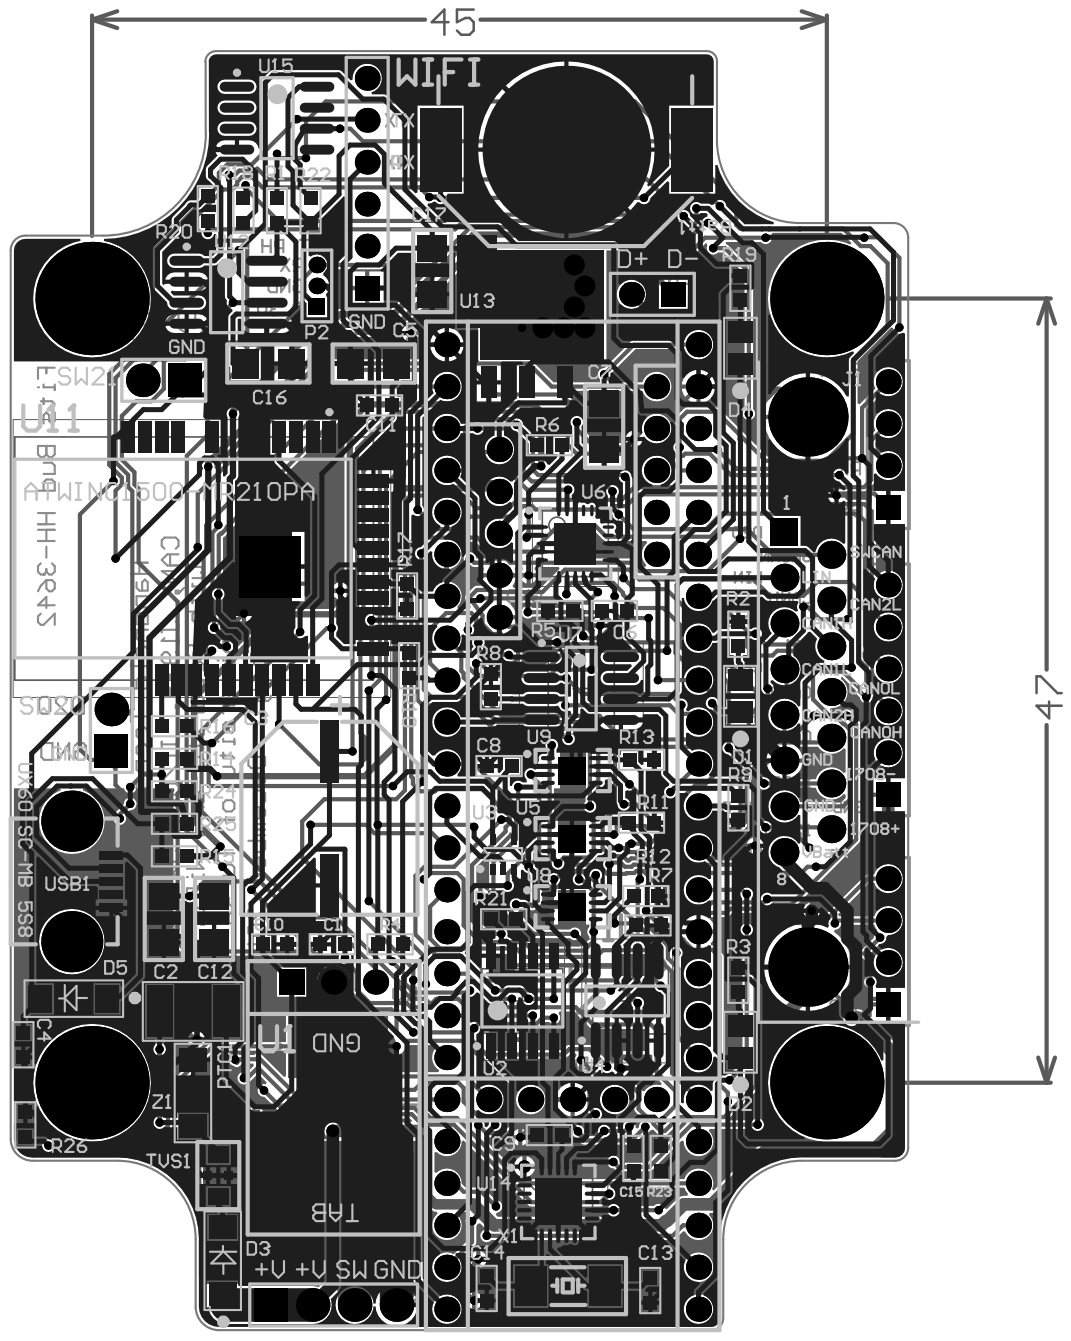
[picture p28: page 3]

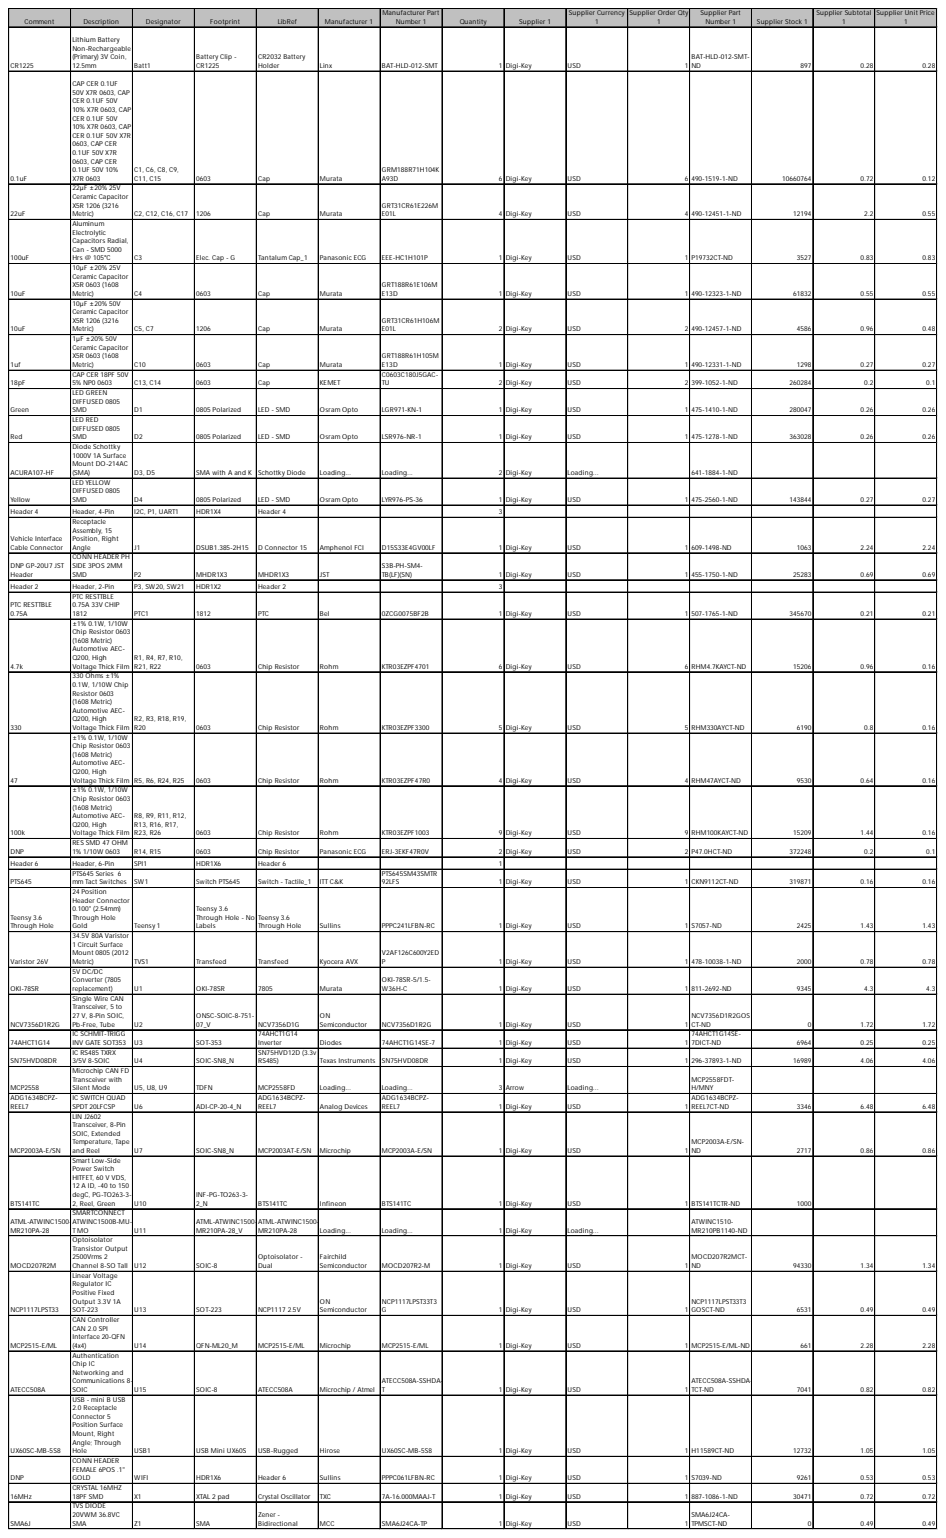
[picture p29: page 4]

Comment | Description | Designator | Footprint | LibRef | Manufacturer 1 | Manufacturer Part Number 1 | Quantity | Supplier 1 | Supplier Currency | Supplier Order Qty | Supplier Part Number 1 | Supplier Stock 1 | Supplier Subtotal | Supplier Unit Price

CR1225 | Lithium Battery Non-Rechargeable (Primary) 3V Coin, 12.5mm | Batt1 | Battery Clip -CR1225 | CR2032 Battery Holder | Linx | BAT-HLD-012-SMT | 1 | Digi-Key | USD | | BAT-HLD-012-SMT-1 ND | 897 | 0.28 | 0.28

0.1uF | CAP CER 0.1UF 50V X7R 0603, CAP CER 0.1UF 50V 10% X7R 0603, CAP CER 0.1UF 50V 10% X7R 0603, CAP CER 0.1UF 50V X7R 0603, CAP CER 0.1UF 50V X7R 0603, CAP CER 0.1UF 50V 10% X7R 0603 | C1, C6, C8, C9, C11, C15 | 0603 | Cap | Murata | GRM188R71H104K A93D | 6 | Digi-Key | USD | | 6 490-1519-1-ND | 10660764 | 0.72 | 0.12

22uF | 22µF ±20% 25V Ceramic Capacitor X5R 1206 (3216 Metric) | C2, C12, C16, C17 | 1206 | Cap | Murata | GRT31CR61E226M E01L | 4 | Digi-Key | USD | | 4 490-12451-1-ND | 12194 | 2.2 | 0.55

100uF | Aluminum Electrolytic Capacitors Radial, Can - SMD 5000 Hrs @ 105°C | C3 | Elec. Cap - G | Tantalum Cap_1 | Panasonic ECG | EEE-HC1H101P | 1 | Digi-Key | USD | | 1 P19732CT-ND | 3527 | 0.83 | 0.83

10uF | 10µF ±20% 25V Ceramic Capacitor X5R 0603 (1608 Metric) | C4 | 0603 | Cap | Murata | GRT188R61E106M E13D | 1 | Digi-Key | USD | | 1 490-12323-1-ND | 61832 | 0.55 | 0.55

10uF | 10µF ±20% 50V Ceramic Capacitor X5R 1206 (3216 Metric) | C5, C7 | 1206 | Cap | Murata | GRT31CR61H106M E01L | 2 | Digi-Key | USD | | 2 490-12457-1-ND | 4586 | 0.96 | 0.48

1uf | 1µF ±20% 50V Ceramic Capacitor X5R 0603 (1608 Metric) | C10 | 0603 | Cap | Murata | GRT188R61H105M E13D | 1 | Digi-Key | USD | | 1 490-12331-1-ND | 1298 | 0.27 | 0.27

18pF | CAP CER 18PF 50V 5% NP0 0603 | C13, C14 | 0603 | Cap | KEMET | C0603C180J5GAC-TU | 2 | Digi-Key | USD | | 2 399-1052-1-ND | 260284 | 0.2 | 0.1

Green | LED GREEN DIFFUSED 0805 SMD | D1 | 0805 Polarized | LED - SMD | Osram Opto | LGR971-KN-1 | 1 | Digi-Key | USD | | 1 475-1410-1-ND | 280047 | 0.26 | 0.26

Red | LED RED DIFFUSED 0805 SMD | D2 | 0805 Polarized | LED - SMD | Osram Opto | LSR976-NR-1 | 1 | Digi-Key | USD | | 1 475-1278-1-ND | 363028 | 0.26 | 0.26

ACURA107-HF | Diode Schottky 1000V 1A Surface Mount DO-214AC (SMA) | D3, D5 | SMA with A and K | Schottky Diode | Loading... | Loading... | 2 | Digi-Key | Loading... | | 641-1884-1-ND

Yellow | LED YELLOW DIFFUSED 0805 SMD | D4 | 0805 Polarized | LED - SMD | Osram Opto | LYR976-PS-36 | 1 | Digi-Key | USD | | 1 475-2560-1-ND | 143844 | 0.27 | 0.27

Header 4 | Header, 4-Pin | I2C, P1, UART1 | HDR1X4 | Header 4 | | | 3
Vehicle Interface Cable Connector | Receptacle Assembly, 15 Position, Right Angle | J1 | DSUB1.385-2H15 | D Connector 15 | Amphenol FCI | D15S33E4GV00LF | 1 | Digi-Key | USD | | 1 609-1498-ND | 1063 | 2.24 | 2.24

DNP GP-20U7 JST Header | CONN HEADER PH SIDE 3POS 2MM SMD | P2 | MHDR1X3 | MHDR1X3 | JST | S3B-PH-SM4-TB(LF)(SN) | 1 | Digi-Key | USD | | 1 455-1750-1-ND | 25283 | 0.69 | 0.69

Header 2 | Header, 2-Pin | P3, SW20, SW21 | HDR1X2 | Header 2 | | | 3
PTC RESTTBLE 0.75A | PTC RESTTBLE 0.75A 33V CHIP 1812 | PTC1 | 1812 | PTC | Bel | 0ZCG0075BF2B | 1 | Digi-Key | USD | | 1 507-1765-1-ND | 345670 | 0.21 | 0.21

4.7k | ±1% 0.1W, 1/10W Chip Resistor 0603 (1608 Metric) Automotive AEC-Q200, High Voltage Thick Film | R1, R4, R7, R10, R21, R22 | 0603 | Chip Resistor | Rohm | KTR03EZPF4701 | 6 | Digi-Key | USD | | 6 RHM4.7KAYCT-ND | 15206 | 0.96 | 0.16
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

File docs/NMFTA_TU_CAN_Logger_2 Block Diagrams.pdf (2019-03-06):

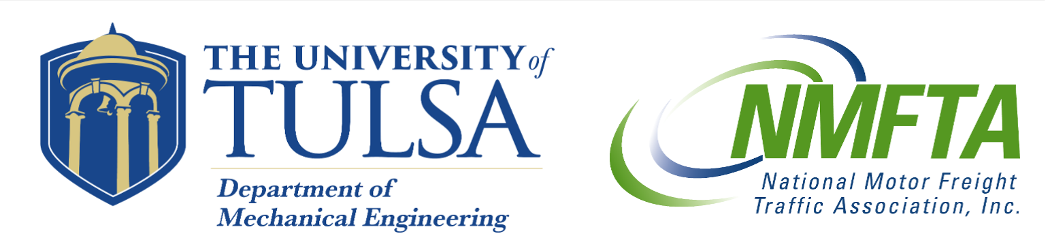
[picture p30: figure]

# National Science Foundation

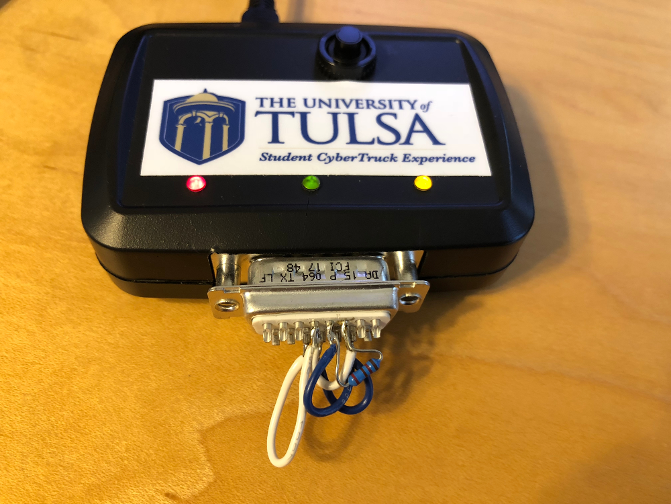
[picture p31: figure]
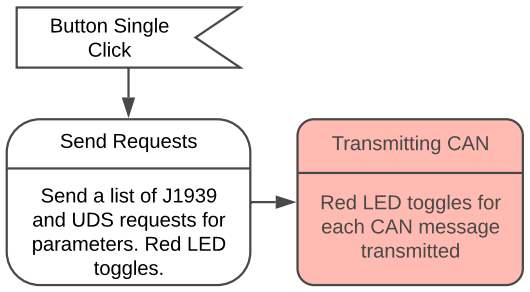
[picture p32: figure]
Transmitting CAN; Red LED toggles for each CAN message transmitted; Button Single Click; Send Requests; Send a list of J1939 and UDS requests for parameters. Red LED toggles.
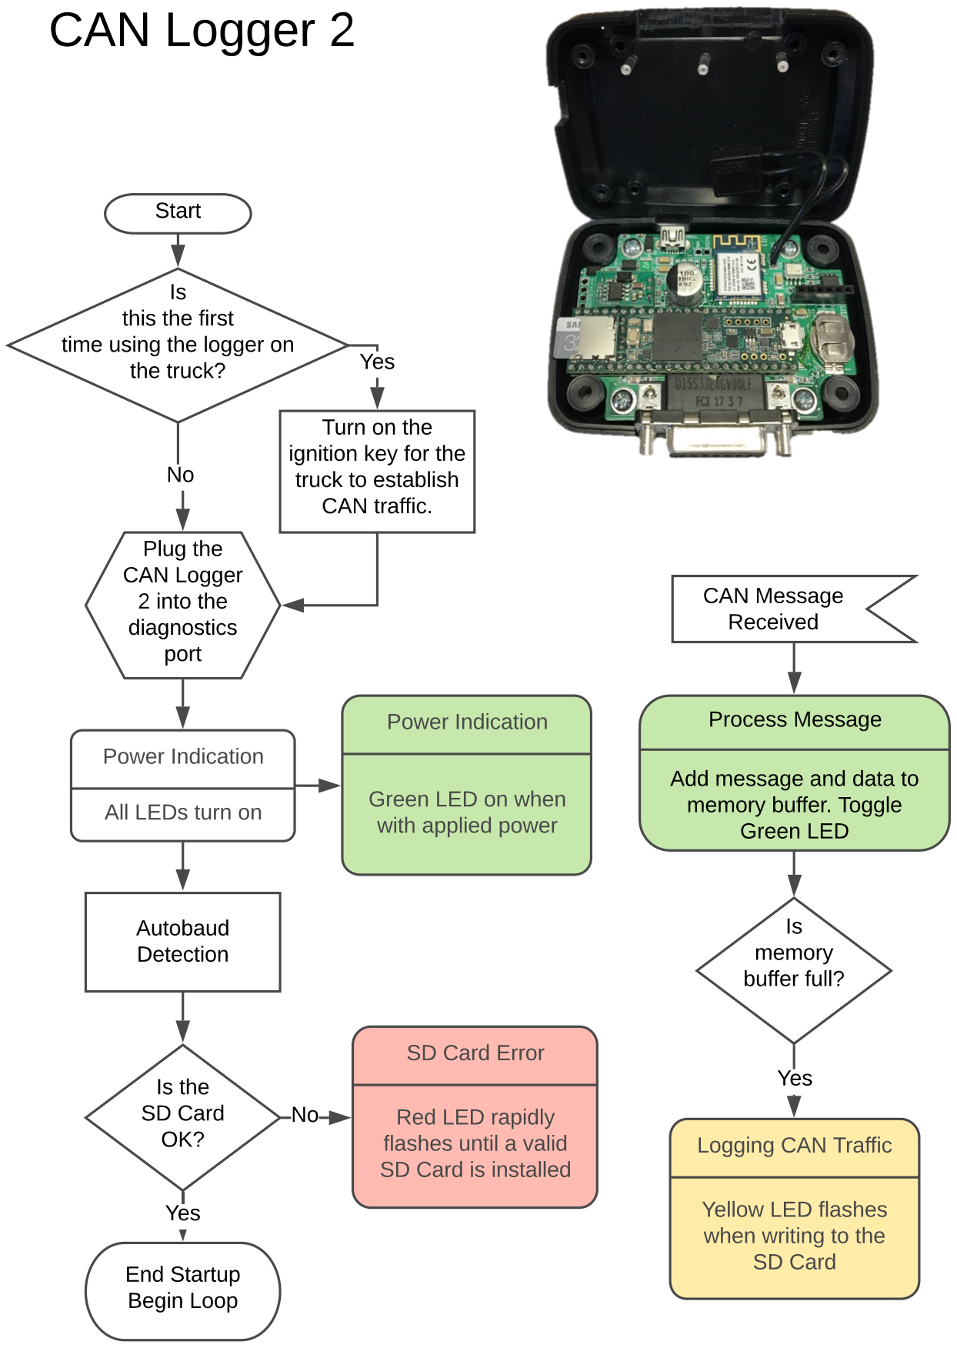
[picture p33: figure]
CAN Logger 2; Power Indication; All LEDs turn on; Start; Is this the first time using the logger on; the truck?; Yes; Turn on the ignition key for the truck to establish CAN traffic.; Plug the CAN Logger; 2 into the diagnostics port; Logging CAN Traffic; Yellow LED flashes when writing to the SD Card; Autobaud Detection; End Startup Begin Loop; CAN Message Received; Process Message; Green LED on when with applied power; Is the SD Card OK?; SD Card Error; Red LED rapidly flashes until a valid SD Card is installed; Is memory; buffer full?

This material is based upon work supported by the National Science Foundation under Grant No. 1715409, titled

### "Detecting and Reconstructing Network Anomalies and Intrusions in Heavy Duty Vehicles"

NMFTA/TU CAN Logger 2 | User Guide | Last Modified by: Jeremy Daily on 6-Mar-2019 | Page 1 of 6

Detecting Error Frames

Red LED flickers when
CAN bus error messages are detected.

Cable is unplugged
(power lost)

Shutdown

Close Current File

Add message and data to memory buffer. Toggle Green LED Button Double Click

Close File

Closes the file and
opens a new one in with the next

sequence number

CAN Bus Error

Process Error Message

Flag a message in the memory buffer by setting the 30th bit. Follow SocketCAN's error message handleing.

LEDs Off

All LEDs turn off while new file is

created

Autobaud
Detection

End Startup
Begin Loop

Continue
Loop

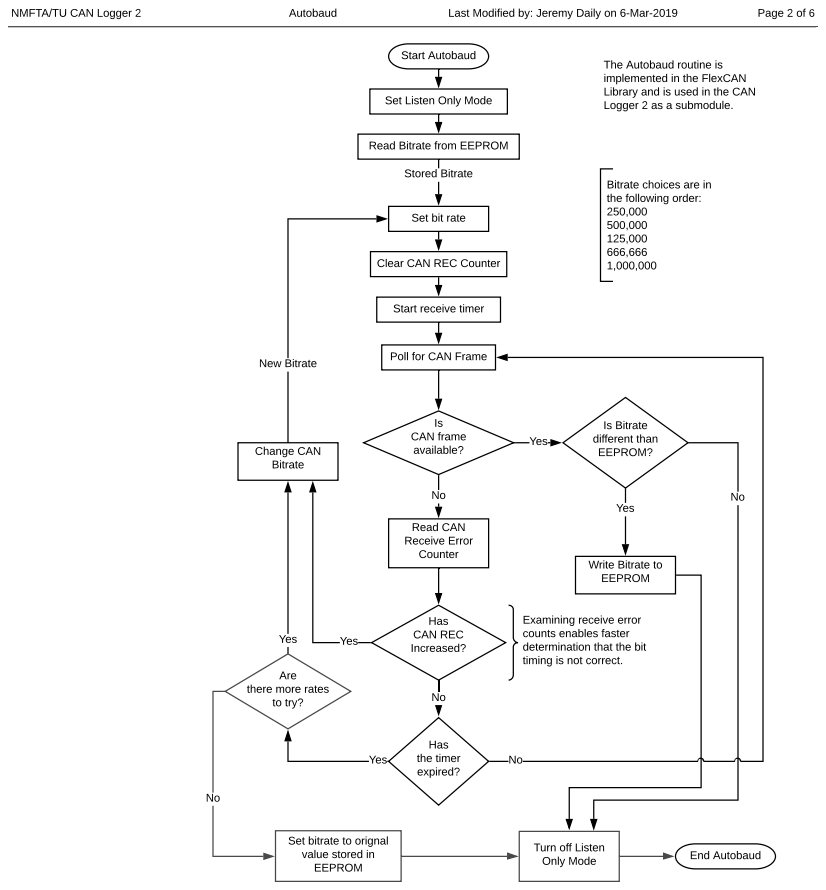
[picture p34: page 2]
Start Autobaud; Stored Bitrate; available?; Has CAN REC Increased?; Change CAN Bitrate; Yes; Is Bitrate different than EEPROM?; Has the timer expired?; New Bitrate; Bitrate choices are in the following order: 250,000 500,000 125,000 666,666 1,000,000; NMFTA/TU CAN Logger 2; Autobaud; Last Modified by: Jeremy Daily on 6-Mar-2019; Page 2 of 6; End Autobaud

The Autobaud routine is
implemented in the FlexCAN
Library and is used in the CAN
Logger 2 as a submodule.

Set Listen Only Mode

Read Bitrate from EEPROM

Set bit rate

Clear CAN REC Counter

Start receive timer

Poll for CAN Frame

Is CAN frame

Read CAN
Receive Error Counter

Write Bitrate to
EEPROM

Examining receive error
counts enables faster
determination that the bit
timing is not correct.

Are
there more rates
to try?

Set bitrate to orignal
value stored in

Turn off Listen Only Mode

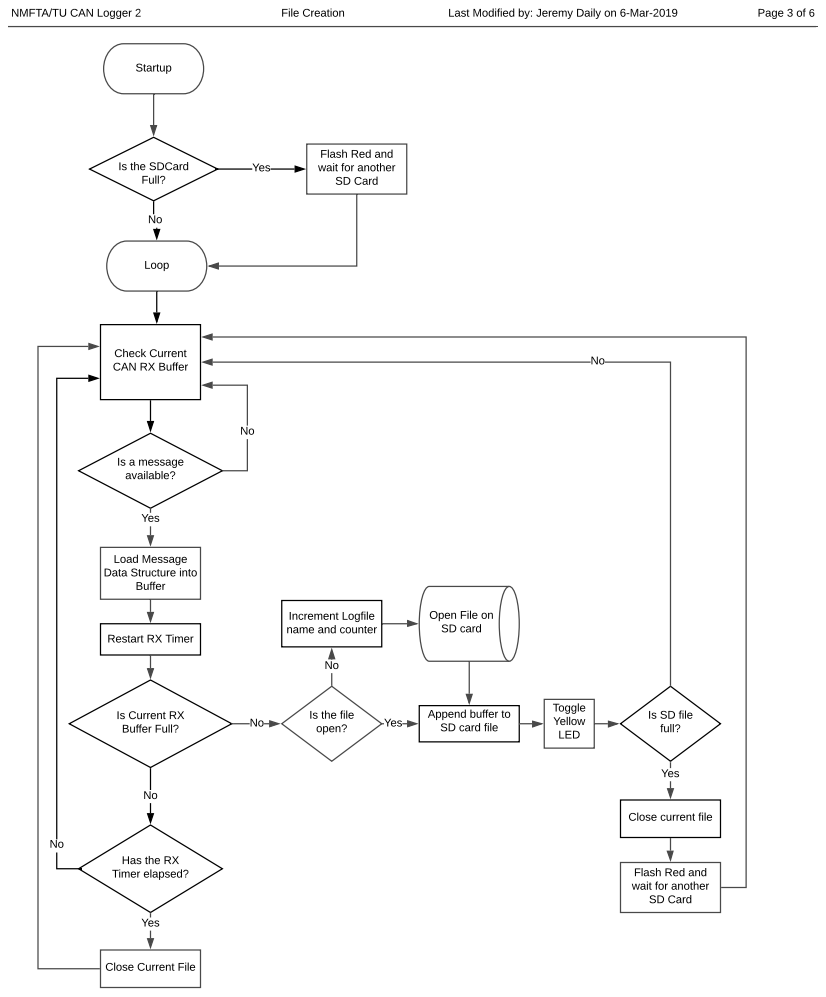
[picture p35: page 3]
Is a message available?; Yes; NMFTA/TU CAN Logger 2; File Creation; Last Modified by: Jeremy Daily on 6-Mar-2019; Page 3 of 6; open?; Toggle Yellow LED; SD Card; Startup; Loop; Buffer

Flash Red and wait for another

Is the SDCard
Full?

Check Current
CAN RX Buffer

Load Message Data Structure into

Increment Logfile
name and counter

Open File on
SD card

Restart RX Timer

Is Current RX
Buffer Full?

Is the file

Append buffer to
SD card file

Is SD file
full?

Close current file

Has the RX
Timer elapsed?

Flash Red and
wait for another
SD Card

Close Current File

Serial Commands | Interrupts

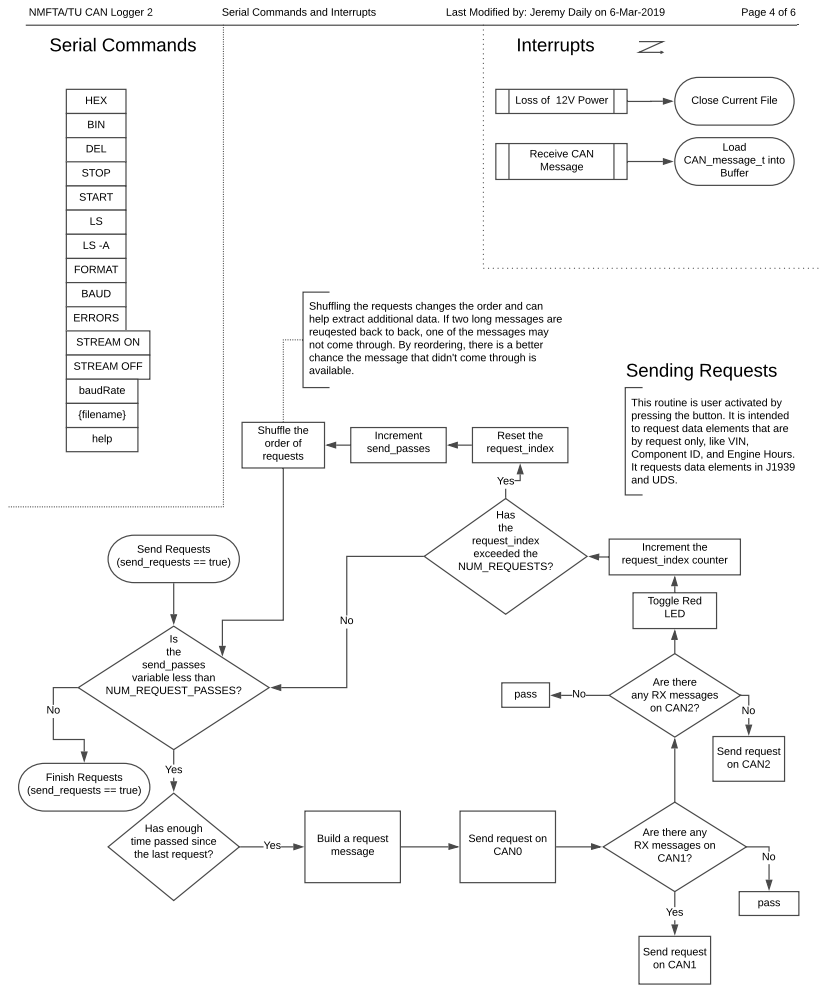
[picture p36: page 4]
NMFTA/TU CAN Logger 2; Serial Commands and Interrupts; Last Modified by: Jeremy Daily on 6-Mar-2019; Page 4 of 6; HEX; BIN; DEL; STOP; START; FORMAT; BAUD; ERRORS; STREAM ON; STREAM OFF; baudRate; {filename}; Loss of 12V Power; Close Current File; Receive CAN Message; Load CAN_message_t into Buffer; help; Send Requests (send_requests == true); Is the send_passes variable less than NUM_REQUEST_PASSES?; Yes; Build a request message; Send request on CAN1; pass; Send request on CAN2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

Shuffling the requests changes the order and can
help extract additional data. If two long messages are
reuqested back to back, one of the messages may
not come through. By reordering, there is a better
chance the message that didn't come through is

This routine is user activated by
pressing the button. It is intended
to request data elements that are
by request only, like VIN, Component ID, and Engine Hours.

It requests data elements in J1939
and UDS.

Are there
any RX messages
on CAN2?

Has enough
time passed since
the last request?

Send request on CAN0

Are there any
RX messages on CAN1?
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

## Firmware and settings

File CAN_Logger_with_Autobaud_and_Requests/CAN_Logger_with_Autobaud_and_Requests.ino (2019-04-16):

/*
 * NMFTA CAN Logger 2 Project
 * 
 * Arduino Sketch for the CAN Logger 2 to record up to 3 CAN channels using
 * a Teensy 3.6. See https://github.com/Heavy-Vehicle-Networking-At-U-Tulsa/CAN-Logger-2
 * for more details.
 * 
 * Written By Dr. Jeremy S. Daily
 * The University of Tulsa
 * Department of Mechanical Engineering
 * 
 * 18 Nov 2018
 * 
 * Released under the MIT License
 *
 * Copyright (c) 2018        Jeremy S. Daily
 *
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
 * 
 * This program logs data to a binary file.  
 * 
 * Samples are logged at regular intervals.  The maximum logging rate
 * depends on the quality of your SD card. 
 * 
 * Much of this sketch was inspired by the examples from https://github.com/greiman/SdFs
 * 
 * The program makes use of the SdFs library
 * 
 */


//included libraries 
#include <SdFs.h>
#include <mcp_can.h>
#include <FlexCAN.h>
#include <OneButton.h>
#include <TimeLib.h>
#include <EEPROM.h>
#include <error.h>
#include <FastCRC.h>

//Get access to a hardware based CRC32 
FastCRC32 CRC32;

// EEPROM memory addresses for creating file names
// The Address 0 and 1 are used for baud rates by the fork FlexCAN submodule -- see src/FlexCAN.h
#define EEPROM_DEVICE_ID_ADDR  4 // 5, 6, 7=00
#define EEPROM_FILE_ID_ADDR    8 // 9, 10, 11 ==00
#define EEPROM_BRAND_NAME_ADDR 12 //13 and 14 ==00

// Setup a limit to turn off the CAN controller after this many messages.
#define ERROR_COUNT_LIMIT 5000

// setup the length for a serial command buffer to control the logger 2.
#define COMMAND_BUFFER_LEN 20 
char command_buffer[COMMAND_BUFFER_LEN];

// Set up the SD Card object
SdFs sd;

#define SD_CONFIG SdioConfig(FIFO_SDIO)

// Create a file object
FsFile binFile;
FsFile baudFile;

String directory_listing;

// All CAN messages are received in the FlexCAN structure
CAN_message_t rxmsg,txmsg;

// Define CAN TXRX Transmission Silent pins
// See the CAN Logger 2 Schematic for the source pins
#define SILENT_0   39
#define SILENT_1   38
#define SILENT_2   37
#define CAN_SWITCH 2
#define BUTTON_PIN 20
#define POWER_PIN  21

// Use the button for multiple inputs: click, doubleclick, and long click.
OneButton button(BUTTON_PIN, true);

String commandString;

/*  code to process time sync messages from the serial port   */
char timeString[100];

// define a counter to reset after each second is counted.
elapsedMicros microsecondsPerSecond;

// Get a uniqueName for the Logger File
char logger_name[4];
bool file_open;
char current_file_name[13];
char prefix[5];
char file_name_prefix[6];
char brand_name[3];
  
  
// Setup the MCP2515 controller
// See the CAN Logger 2 Schematic for the source pins
#define CS_CAN 15
MCP_CAN Can2(CS_CAN); 
//variables for the CAN Message
uint32_t rxId;
uint8_t len;
uint8_t rxBuf[8];
uint8_t ext_flag;

#define FAST_BLINK_TIME 50 //milliseconds
#define SLOW_BLINK_TIME 500 //milliseconds

//Setup LEDs
#define GREEN_LED 6
#define RED_LED 14
#define YELLOW_LED 5

boolean GREEN_LED_state;
boolean RED_LED_state;
boolean YELLOW_LED_state;

elapsedMillis GREEN_LED_Slow_Timer;
elapsedMillis RED_LED_Slow_Timer;
elapsedMillis YELLOW_LED_Slow_Timer;

elapsedMillis GREEN_LED_Fast_Timer;
elapsedMillis RED_LED_Fast_Timer;
elapsedMillis YELLOW_LED_Fast_Timer;

boolean GREEN_LED_slow_blink_state;
boolean RED_LED_slow_blink_state;
boolean YELLOW_LED_slow_blink_state;

boolean GREEN_LED_fast_blink_state;
boolean RED_LED_fast_blink_state;
boolean YELLOW_LED_fast_blink_state;


// Setup a counter to keep track of the filename
char current_file[4];

// Keep track of the CAN Channel (0, 1, or 2, where 2 is MCP CAN)
uint8_t current_channel;


// There are 2 data buffers that get switched. We need to know which one
// we are using and where we are in the buffer.
#define CAN_FRAME_SIZE 25
#define MAX_MESSAGES 19
#define BUFFER_POSITION_LIMIT (CAN_FRAME_SIZE * MAX_MESSAGES)
#define BUFFER_SIZE 512
uint8_t data_buffer[BUFFER_SIZE];
uint16_t current_position;

//Counter and timer to keep track of transmitted messages
#define TX_MESSAGE_TIME 2 //milliseconds
uint32_t TXCount0 = 0;
uint32_t TXCount1 = 0;
uint32_t TXCount2 = 0;
elapsedMillis TXTimer0;
elapsedMillis TXTimer1;
elapsedMillis TXTimer2;

// To use a button to send requests, we need to track it.
#define NUM_REQUEST_PASSES 3
#define REQUEST_TIMING 250 //milliseconds
elapsedMillis send_request_timer;
elapsedMillis send_iso_request_timer;
boolean send_requests;
boolean send_iso_requests;
uint16_t request_index;
uint16_t iso_request_index;
uint8_t send_passes;
uint8_t send_iso_passes;

#define NUM_REQUESTS 27
uint16_t request_pgn[NUM_REQUESTS] = {
  65261, // Cruise Control/Vehicle Speed Setup
  65214, // Electronic Engine Controller 4
  65259, // Component Identification
  65242, // Software Identification
  65244, // Idle Operation
  65260, // Vehicle Identification
  65255, // Vehicle Hours
  65253, // Engine Hours, Revolutions
  65257, // Fuel Consumption (Liquid)
  65256, // Vehicle Direction/Speed
  65254, // Time/Date
  65211, // Trip Fan Information
  65210, // Trip Distance Information
  65209, // Trip Fuel Information (Liquid)
  65207, // Engine Speed/Load Factor Information
  65206, // Trip Vehicle Speed/Cruise Distance Information
  65205, // Trip Shutdown Information
  65204, // Trip Time Information 1
  65200, // Trip Time Information 2
  65250, // Transmission Configuration
  65203, // Fuel Information (Liquid)
  65201, // ECU History
  65168, // Engine Torque History
  64981, // Electronic Engine Controller 5
  64978, // ECU Performance
  64965, // ECU Identification Information
  65165  // Vehicle Electrical Power #2
};

#define NUM_ISO_REQUESTS 9
uint16_t iso_request[NUM_ISO_REQUESTS] = {
  0xF195, //System Supplier ECU Software Version Number
  0xF190, //Vehicle Identfication Number
  0xF193, //System Supplier ECU Hardware Version Number
  0xF18C, //ECU Serial Number
  0xF180, //Boot Software Identfication
  0xF181, //Application Software Identfication
  0xF186, //Active Diagnostic Session
  0xF192, //System Supplier ECU Hardware Number
  0xF197, //System Name or Engine Type
};
    
//Create a counter and timer to keep track of received message traffic
#define RX_TIME_OUT 1000 //milliseconds
elapsedMillis RXTimer;
uint32_t RXCount0 = 0;
uint32_t RXCount1 = 0;
uint32_t RXCount2 = 0;
elapsedMillis lastCAN0messageTimer;
elapsedMillis lastCAN1messageTimer;
elapsedMillis lastCAN2messageTimer;
uint32_t ErrorCount0 = 0;
uint32_t ErrorCount1 = 0;
uint32_t ErrorCount2 = 0;

// Should we stream the CAN frame to the serial port? Serial 
// can't keep up with heavy CAN bus loads, so this is default to false.
bool stream = false;

// Track the state of the user's desire to log. This can toggle based 
// on user input.
bool recording = true;

/*
 * The load_buffer() function maps the received CAN message into
 * the positions in the buffer to store. Each buffer is 512 bytes.
 * 20 CAN messages can fit in the buffer since they are 25 bytes long.
 * Note: an additional channel byte was added when comparing to the 
 * NMFTA CAN Logger 1 files. 
 * 
 * Use this function to understand how the the binary file format was created.
 * When reading the binary, be sure to read it in 512 byte chunks.
 */
void load_buffer(){
  // reset the timer
  RXTimer = 0;

  //Toggle the LED
  GREEN_LED_state = !GREEN_LED_state;
  digitalWrite(GREEN_LED, GREEN_LED_state);
    
  data_buffer[current_position] = current_channel;
  current_position += 1;
  
  time_t timeStamp = now();
  memcpy(&data_buffer[current_position], &timeStamp, 4);
  current_position += 4;
  
  memcpy(&data_buffer[current_position], &rxmsg.micros, 4);
  current_position += 4;

  memcpy(&data_buffer[current_position], &rxmsg.id, 4);
  current_position += 4;

  // Store the message length as the most significant byte and use the 
  // lower 24 bits to store the microsecond counter for each second.
  uint32_t DLC = (rxmsg.len << 24) | (0x00FFFFFF & uint32_t(microsecondsPerSecond));
  memcpy(&data_buffer[current_position], &DLC, 4);
  current_position += 4;

  memcpy(&data_buffer[current_position], &rxmsg.buf, 8); 
  current_position += 8;

  if ((rxmsg.id & CAN_ERR_FLAG) == CAN_ERR_FLAG){
    RED_LED_state = !RED_LED_state;
    digitalWrite(RED_LED, RED_LED_state);  
  }
  
  // Check the current position and see if the buffer needs to be written 
  // to the SD card.
  check_buffer();
}

void check_buffer(){
  //Check to see if there is anymore room in the buffer
  if (current_position >= BUFFER_POSITION_LIMIT){ //max number of messages
    //Create a file if it is not open yet
    if (!file_open) {
      open_binFile();
      Serial.print("Opened File ");
      Serial.println(current_file_name);
    }
  
    uint32_t start_micros = micros();
    
    // Write the beginning of each line in the 512 byte block
    sprintf(prefix,"CAN2");
    memcpy(&data_buffer[0], &prefix, 4);
    current_position = 4;
    
    memcpy(&data_buffer[479], &RXCount0, 4);
    memcpy(&data_buffer[483], &RXCount1, 4);
    memcpy(&data_buffer[487], &RXCount2, 4);
    
    data_buffer[491] = Can0.readREC();
    data_buffer[492] = Can1.readREC();
    data_buffer[493] = uint8_t(Can2.errorCountRX());
    
    data_buffer[494] = Can0.readTEC();
    data_buffer[495] = Can1.readTEC();
    data_buffer[496] = uint8_t(Can2.errorCountTX());
    
    // Write the filename to each line in the 512 byte block
    memcpy(&data_buffer[497], &current_file_name, 8);
  
    uint32_t checksum = CRC32.crc32(data_buffer, 508);
    memcpy(&data_buffer[508], &checksum, 4);
    
    if (BUFFER_SIZE != binFile.write(data_buffer, BUFFER_SIZE)) {
      Serial.println("write failed");
      sdErrorFlash(); 
    }

    //Reset the record
    memset(&data_buffer,0xFF,512);
    
    //Record write times for the previous frame, since the existing frame was just written
    uint32_t elapsed_micros = micros() - start_micros;
    memcpy(&data_buffer[505], &elapsed_micros, 3);
 
    //Toggle LED to show SD card writing
    YELLOW_LED_state = !YELLOW_LED_state;
    digitalWrite(YELLOW_LED,YELLOW_LED_state);
  }
}

void print_hex(){
  turn_recording_off();
  turn_streaming_off();
  char line[512];
  if (!binFile.isOpen()) close_binFile();
  if (sd.exists(current_file_name)){
    binFile.open(current_file_name, O_READ);
    while (binFile.read(line, sizeof(line)) > 0) {
      for (uint16_t i = 0; i < sizeof(line); i++){
        char disp[4];
        sprintf(disp,"%02X ",line[i]);
        Serial.print(disp);
      }  
      Serial.println();
    }
    binFile.close();
    setup();
  }
  else
  {
    Serial.println("Current file does not exist");
  }
}

void delete_file(char delete_file_name[]){
  if (!binFile.isOpen()) close_binFile();
  // Remove any existing file.
  if (sd.exists(delete_file_name)) {
    sd.remove(delete_file_name); 
  }
  else
  {
    Serial.println("Current file does not exist");
  }
}

void stream_binary(char stream_file_name[]){
  turn_streaming_off();
  turn_recording_off();
  char line[512];
  if (!binFile.isOpen()) close_binFile();
  if (sd.exists(stream_file_name)){
    binFile.open(stream_file_name, O_READ);
    while (binFile.read(line, sizeof(line)) > 0) 
    {
      for (uint16_t i = 0; i < sizeof(line); i++)
      {
        Serial.write(line[i]);
      }  
    }
    binFile.close();
    setup();
  }
  else
  {
    Serial.println("Current file does not exist");
  }
}

void stream_text(char stream_file_name[]){
  turn_streaming_off();
  FsFile textFile; 
  if (sd.exists(stream_file_name))
  {
    textFile.open(stream_file_name, O_READ);
    while (textFile.available()) 
    {
      Serial.write(textFile.read());
    }
  }
  else
  {
    Serial.println("Current file does not exist");
  }
}

/*
 * Check to make sure the characters are valid in a character array
 * This is used to check the data coming from EEPROM.
 */
bool isFileNameValid( const char *fileName )
{
  char c;
  while ( (c = *fileName++) )
    if ( c != '.' && !isalnum(c) )
      return false;
  return true;
}

/*
 * Reset the microsecond counter and return the realtime clock
 * This function requires the sync interval to be exactly 1 second.
 */
time_t getTeensy3Time(){
  microsecondsPerSecond = 0;
  return Teensy3Clock.get();
}

/*
 * Routine to enable date and time for the sdcard 
 * file system
 */
void dateTime(uint16_t* FSdate, uint16_t* FStime) {
  // Return date using FS_DATE macro to format fields.
  *FSdate = FS_DATE(year(), month(), day());

  // Return time using FS_TIME macro to format fields.
  *FStime = FS_TIME(hour(), minute(), second());
}


/*
 * Routines for the Microchip MCP2515 CAN Controller on Can2
 * This third CAN channel is wired to the J1708 pins (F and G) found
 * on some newer PACCAR trucks.
 */
void send_Can2_message(CAN_message_t &txmsg){
  if (TXTimer2 >= TX_MESSAGE_TIME){
    //Send message in format: ID, Standard (0) or Extended ID (1), message length, txmsg
    Can2.sendMsgBuf(txmsg.id, 1, txmsg.len, txmsg.buf);  
    TXCount2++;
    TXTimer2 = 0;
  }  
}


/*
 * Routines for the FlexCAN Controller on Can0 and Can1
 * Can0 is usually J1939
 */
void send_Can0_message(CAN_message_t &txmsg){
  if (TXTimer0 >= TX_MESSAGE_TIME){    
    //Send message in FlexCAN format
    Can0.write(txmsg);
    TXCount0++;
    TXTimer0 = 0;   
  }
}
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
void loop(void) {
  // monitor the CAN channels
  if (Can0.read(rxmsg)){
    RXCount0++;
    current_channel = 0;
    rx_message_routine(RXCount0);
  }
  if (Can1.read(rxmsg)){
    RXCount1++;
    current_channel = 1;
    rx_message_routine(RXCount1);
  }
  if (Can2.readMsgBuf(&rxId, &ext_flag, &len, rxBuf) == CAN_OK){
    RXCount2++;
    memcpy(&rxmsg.buf, rxBuf, 8);
    rxmsg.len = uint8_t(len);
    rxmsg.id = uint32_t(rxId);
    current_channel = 2;
    rx_message_routine(RXCount2);
  } 

  // Close the file if messages stop showing up.
  if (RXTimer >= RX_TIME_OUT && file_open){
    close_binFile();
    RXTimer = 0;
  }
  
  led_blink_routines();
  
  // Send requests for additional data if needed
  if (send_requests){
    if (send_passes < NUM_REQUEST_PASSES){
      if (send_request_timer > REQUEST_TIMING){
        send_request_timer = 0;
        txmsg.len = 3;
        txmsg.id = 0x18EAFFF9;
        txmsg.buf[0] = (request_pgn[request_index] & 0x0000FF);
        txmsg.buf[1] = (request_pgn[request_index] & 0x00FF00) >> 8 ;
        txmsg.buf[2] = (request_pgn[request_index] & 0xFF0000) >> 16; //These are in reverse byte order.
        send_Can0_message(txmsg);
        if (RXCount1 > 0) send_Can1_message(txmsg);
        if (RXCount2 > 0) send_Can2_message(txmsg);
        //Toggle LED light as messages are sent
        RED_LED_state = !RED_LED_state;                       
        digitalWrite(RED_LED,RED_LED_state);  
        request_index++;
        if (request_index >= NUM_REQUESTS) {
          request_index = 0;
          send_passes++;
          //shuffle
          //Serial.println("Shuffling Requests");
          for (int i = 0; i < NUM_REQUESTS; i++) {
            int j = random(i, NUM_REQUESTS);
            auto temp = request_pgn[i];
            request_pgn[i] = request_pgn[j];
            request_pgn[j] = temp;
          }
        }
      }
    }
    else
    {
      send_passes = 0;
      send_requests = false;
      send_iso_requests = true;
      send_iso_request_timer = 0;
    }
  }
  else if (send_iso_requests)
  {
    if (send_iso_passes < NUM_REQUEST_PASSES){
      if (send_iso_request_timer > REQUEST_TIMING){
        send_iso_request_timer = 0;
        txmsg.len = 8;
        txmsg.id = 0x18DAFFF9;
        txmsg.buf[0] = 0x02;
        txmsg.buf[1] = (iso_request[request_index] & 0x00FF) >> 0 ;
        txmsg.buf[2] = (iso_request[request_index] & 0xFF00) >> 8; //These are in reverse byte order.
        send_Can0_message(txmsg);
        if (RXCount1 > 0) send_Can1_message(txmsg); //only send something if the network is alive
        if (RXCount2 > 0) send_Can2_message(txmsg); //only send something if the network is alive
        //Toggle LED light as messages are sent
        RED_LED_state = !RED_LED_state;                       
        digitalWrite(RED_LED,RED_LED_state);  
        request_index++;
        if (request_index >= NUM_ISO_REQUESTS) {
          request_index = 0;
          send_iso_passes++;
          //shuffle
          //Serial.println("Shuffling Requests");
          for (int i = 0; i < NUM_ISO_REQUESTS; i++) {
            int j = random(i, NUM_ISO_REQUESTS);
            auto temp = iso_request[i];
            iso_request[i] = request_pgn[j];
            iso_request[j] = temp;
          }
        }
      }
    }
    else
    {
      send_iso_passes = 0;
      send_iso_requests = false;
    }
  }
  
  if (Serial.available() >= 2) {
    commandString = Serial.readStringUntil('\n');
    commandString.toCharArray(command_buffer, COMMAND_BUFFER_LEN);
    // Count the number of valid characters
    uint8_t j = 0;
    while ((isAlphaNumeric(command_buffer[j]) or command_buffer[j] == ' ') and j < COMMAND_BUFFER_LEN) j++;
    if (commandString.length() == j){ // check to make sure no non-ascii inputs are being interpreted 
      memset(command_buffer,0,COMMAND_BUFFER_LEN);
      if      (commandString.equalsIgnoreCase("HEX"))        print_hex();
      else if (commandString.equalsIgnoreCase("BIN"))        stream_binary(current_file_name);
      else if (commandString.equalsIgnoreCase("STOP"))       turn_recording_off();
      else if (commandString.equalsIgnoreCase("START"))      turn_recording_on();
      else if (commandString.equalsIgnoreCase("NEW"))        close_binFile();
      else if (commandString.equalsIgnoreCase("DF"))         sd_capacity();
      else if (commandString.equalsIgnoreCase("LS"))         list_files();
      else if (commandString.equalsIgnoreCase("LS A"))       list_files_a();
      else if (commandString.equalsIgnoreCase("FORMAT"))     format_sd_card();
      else if (commandString.equalsIgnoreCase("BAUD"))       display_baud_rate();
      else if (commandString.equalsIgnoreCase("ERRORS"))     display_error_count();
      else if (commandString.equalsIgnoreCase("STREAM ON"))  turn_streaming_on();
      else if (commandString.equalsIgnoreCase("STREAM OFF")) turn_streaming_off();
      else if (commandString.equalsIgnoreCase("REQUEST ON")) turn_requests_on();
      else if (commandString.equalsIgnoreCase("REQUEST OFF"))turn_requests_off();
      else if (commandString.startsWith("DEL ")){
        char delete_file_name[13];
        commandString.remove(0,4);
        commandString.toCharArray(delete_file_name,13);
        delete_file(delete_file_name);
      }
      else if (commandString.equalsIgnoreCase("BAUDRATE")){
        char stream_file_name[13]; 
        strcpy(stream_file_name,"baudRate.txt");
        stream_text(stream_file_name);
      }
      else if (commandString.startsWith(brand_name)){
        char stream_file_name[13]; 
        commandString.toCharArray(stream_file_name,13);
        stream_binary(stream_file_name);     
      }
      else if (commandString.startsWith("ID ")){
        commandString.remove(0,3);
        if (commandString.length() == 3){
          commandString.toUpperCase();
          commandString.toCharArray(logger_name,4);
          EEPROM.put(EEPROM_DEVICE_ID_ADDR,logger_name);
          Serial.print("Set Device ID to ");
          Serial.println(logger_name);
        }
        else {
          Serial.println("Improper ID Length");
        }
      }
      else if (commandString.startsWith("COUNT")){
        commandString.remove(0,6);
        commandString.toUpperCase();
        char input_count[4];
        commandString.toCharArray(input_count,4);
        memset(current_file,0,4);
        memset(current_file,'0',3);
        if (commandString.length() == 3) {
          current_file[0] = input_count[0];
          current_file[1] = input_count[1];
          current_file[2] = input_count[2];
        }
        else if (commandString.length() == 2){
          current_file[1] = input_count[0];
          current_file[2] = input_count[1];
        }
        else if (commandString.length() == 1){
          current_file[2] = input_count[0];
        }
        if (isFileNameValid(current_file)){
          EEPROM.put(EEPROM_FILE_ID_ADDR,current_file);
          Serial.print("Set current file to ");
          Serial.println(current_file);
        }
        else
        {
          Serial.println("Not a valid file count.");
        }
      }    
      else if (commandString.equalsIgnoreCase("HELP")){
        Serial.println(F("List of available commands:"));
        Serial.println(F("HEX         (Stream the latest log file in printable hexadecimal)"));
        Serial.println(F("BIN         (Stream the latest log file in binary format to the serial port)"));
        Serial.println(F("DEL [file-name.bin] (Delete the chosen file in the SD card)"));
        Serial.println(F("STOP        (Turn recording off)"));
        Serial.println(F("START       (Turn recording on)"));
        Serial.println(F("NEW         (Start a new log file)"));
        Serial.println(F("DF          (Show SD card capacity)"));
        Serial.println(F("LS          (List files in the SD card)"));
        Serial.println(F("LS A        (List files in the SD card with time stamp)"));
        Serial.println(F("FORMAT      (Format the SD card)"));
        Serial.println(F("BAUD        (Display current baudrate on the channels)"));
        Serial.println(F("ERRORS      (Display error count on the channels)"));
        Serial.println(F("REQUEST ON  (Turn requests on)"));
        Serial.println(F("REQUEST OFF (Turn request off)"));
        Serial.println(F("STREAM ON   (Start sending interpreted CAN Frames to the Serial port)"));
        Serial.println(F("STREAM OFF  (Stop sending interpreted CAN Frames to the Serial port)"));
        Serial.println(F("BAUDRATE    (Show the baudrate in each log file)"));
        Serial.println(F("COUNT [abc] (Set the file index to a 3 digit alphanumeric code abc)"));
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

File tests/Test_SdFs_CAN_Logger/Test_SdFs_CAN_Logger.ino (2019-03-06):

/*
 * NMFTA CAN Logger Project
 * 
 * Arduino Sketch to test the ability to receive and log CAN messages
 * 
 * Written By Dr. Jeremy S. Daily
 * The University of Tulsa
 * Department of Mechanical Engineering
 * 
 * 18 Nov 2018
 * 
 * Released under the MIT License
 *
 * Copyright (c) 2016        Jeremy S. Daily
 *
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
 * 
 * This program logs data to a binary file.  
 * 
 * Samples are logged at regular intervals.  The maximum logging rate
 * depends on the quality of your SD card. 
 * 
 * 
 * Much of this sketch was inspired by the examples from https://github.com/greiman/SdFs
 * 
 * The program makes use of the SdFs library
 * 
 */


//included libraries 
#include <SdFs.h>
#include <mcp_can.h>
#include <FlexCAN.h>
#include <Bounce2.h>
#include <TimeLib.h>

// Instantiate a Bounce object to debounce the pushbutton
Bounce debouncer = Bounce(); 

// Set up the SD Card object
SdFs sd;

// Create a file object
FsFile binFile;

// All CAN messages are received in the FlexCAN structure
CAN_message_t rxmsg;

// Define CAN TXRX Transmission Silent pins
// See the CAN Logger 2 Schematic for the source pins
#define SILENT_0   39
#define SILENT_1   38
#define SILENT_2   37
#define CAN_SWITCH 2
#define BUTTON_PIN 21


// Set CS to pin 15, according to schematics
#define CS_CAN 15
MCP_CAN Can2(CS_CAN); 

elapsedMicros microsecondsPerSecond;
elapsedMillis lastCANmessageTimer;
elapsedMillis LEDblinkTimer;
elapsedMillis txTimer;

//Set LEDs
#define green_LED 6
#define red_LED 14
#define yellow_LED 5

boolean green_LED_state;
boolean red_LED_state;
boolean yellow_LED_state;

// Setup a counter to keep track of the filename
uint16_t current_file;
// Keep track of the CAN Channel (0, 1, or 2, where 2 is MCP CAN)
uint8_t current_channel;
//There are 2 data buffers that get switched
uint8_t current_buffer;
uint16_t current_position;

#define MAX_MESSAGES 20
#define BUFFER_POSITION_LIMIT 499
#define BUFFER_SIZE 512
uint8_t data_buffer[2][BUFFER_SIZE];

//Counter to keep track
uint32_t TXCount = 0;

//Create a counter to keep track of message traffic
uint32_t RXCount0 = 0;
uint32_t RXCount1 = 0;

boolean file_open;

void load_buffer(){
  // reset the timer
  lastCANmessageTimer = 0;
  
  data_buffer[current_buffer][current_position] = current_channel;
  current_position += 1;
  
  time_t timeStamp = now();
  memcpy(&data_buffer[current_buffer][current_position], &timeStamp, 4);
  current_position += 4;
  
  uint32_t usec = micros();
  memcpy(&data_buffer[current_buffer][current_position], &usec, 4);
  current_position += 4;

  uint32_t ID =  rxmsg.id;
  memcpy(&data_buffer[current_buffer][current_position], &ID, 4);
  current_position += 4;
  
  uint32_t DLC = (rxmsg.len << 24) | (0x00FFFFFF & uint32_t(microsecondsPerSecond));
  memcpy(&data_buffer[current_buffer][current_position], &DLC, 4);
  current_position += 4;

  memcpy(&data_buffer[current_buffer][current_position], &rxmsg.buf, 8); 
  current_position += 8;
}

/*  code to process time sync messages from the serial port   */
#define TIME_HEADER  "T"   // Header tag for serial time sync message
#define DEFAULT_TIME  1357041600 // Jan 1 2013 

uint32_t processSyncMessage() {
  uint32_t pctime = 0L;
  
  if(Serial.find(TIME_HEADER)) {
     pctime = Serial.parseInt();
     if( pctime < DEFAULT_TIME) { // check the value is a valid time (greater than Jan 1 2013)
       pctime = 0L; // return 0 to indicate that the time is not valid
     }
  }
  return pctime;
}

time_t getTeensy3Time(){
  microsecondsPerSecond = 0;
  return Teensy3Clock.get();
}

void dateTime(uint16_t* FSdate, uint16_t* FStime) {
  // Return date using FS_DATE macro to format fields.
  *FSdate = FS_DATE(year(), month(), day());

  // Return time using FS_TIME macro to format fields.
  *FStime = FS_TIME(hour(), minute(), second());
}

void send_mcp_messages(){
  //if (txTimer >= 10){
    txTimer = 0;
  
    //Convert the 32-bit timestamp into 4 bytes with the most significant byte (MSB) first (Big endian).
    uint32_t sysMicros = micros();
    byte txmsg[8];
    txmsg[0] = (sysMicros & 0xFF000000) >> 24;
    txmsg[1] = (sysMicros & 0x00FF0000) >> 16;
    txmsg[2] = (sysMicros & 0x0000FF00) >>  8;
    txmsg[3] = (sysMicros & 0x000000FF);
    
    //Convert the 32-bit transmit counter into 4 bytes with the most significant byte (MSB) first (Big endian). 
    
    txmsg[4] = (TXCount & 0xFF000000) >> 24;
    txmsg[5] = (TXCount & 0x00FF0000) >> 16;
    txmsg[6] = (TXCount & 0x0000FF00) >>  8;
    txmsg[7] = (TXCount & 0x000000FF);
    
    //Send messaeg in format: ID, Standard (0) or Extended ID (1), message length, txmsg
    Can2.sendMsgBuf(0x1CFEFE00, 1, 1, txmsg);  
    
    //Toggle LED light as messages are sent
    red_LED_state = !red_LED_state;                       
    digitalWrite(red_LED,red_LED_state);
    
    //Print on serial for every sent message
    Serial.print("Message Sent: ");
    Serial.println(TXCount);
    TXCount++;
  //}  
}


//A generic CAN Frame print function for the Serial terminal
void printFrame(CAN_message_t rxmsg, uint8_t channel, uint32_t RXCount)
{
  char CANdataDisplay[50];
  sprintf(CANdataDisplay, "%d %12lu %12lu %08X %d %d", channel, RXCount, micros(), rxmsg.id, rxmsg.ext, rxmsg.len);
  Serial.print(CANdataDisplay);
  for (uint8_t i = 0; i < rxmsg.len; i++) {
    char CANBytes[4];
    sprintf(CANBytes, " %02X", rxmsg.buf[i]);
    Serial.print(CANBytes);
  }
  Serial.println();
}

void errorFlash(){
  while(true){
    digitalWrite(red_LED,HIGH);
    delay(50);
    digitalWrite(red_LED,LOW);
    delay(50);
  }
}
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

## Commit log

2018-05-31 Initial Documentation
    [Additional Circuits - Handheld - Rev 2.SchDoc, Handheld Logger Bud HH3642 rev2.PcbDoc, Handheld Teensy 3.6 Logger Rev 2 Bill of Materials.csv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]
2018-06-01 LED with Button Test
2018-06-01 LED Test with Button
2018-06-05 Update readme test code
    For LED, CAN0 and 1, and MCP2515
2018-08-08 New Arduino Example
2018-08-31 Code for flooding the BUS while pressing the button
2018-11-11 Wifi and Flooding the bus with button
    Update ReadMe with Wifi and flooding the BUS with button. Add WiFi Library, WiFi test code and flooding the BUS with button test code.
2018-11-16 Cleaned bus flood on button
2018-11-24 Address Correction for EEPROM
    [CAN_Logger_with_Autobaud_and_Requests.ino]
2018-11-25 Added CRC32 for each SD card block
    Reduced the number of frames down to 19 and added meta data like error counts for all three channels.
    [SD Card Data Structure.xlsx]
2018-11-26 Added File Counter to include Letters and Numbers
    Added commented code to reset file counters and set ID.
    [CAN_Logger_with_Autobaud_and_Requests.ino]
2018-11-26 Added Print and Stream Binary Serial Commands
2018-11-26 Added Requests By a Button
2018-11-28 Removed Requests for long press
    [SD Card Data Structure.xlsx]
2018-12-07 Added Serial Commands
    Enables following serial commands:
    HEX
    BIN
    DEL
    STOP
    START
    NEW
    LS
    LS -A
    FORMAT
    BAUD
    ERRORS
    STREAM ON
    STREAM OFF
    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
    [CAN_Logger_with_Autobaud_and_Requests.ino]
2018-12-07 Added File closing interrupt if power is lost.
2018-12-10 Added flow control responses for ISO 14229
2019-01-30 Added current libraries
2019-03-06 Update HELP Command
    Add ID command to change device ID in serial command. Update HELP list
2019-03-12 Update CAN_Logger_with_Autobaud_and_Requests.ino
    Add rx_message_rountine() to can1 and can2, change printFrame in rx_message_routine to current_channel instead of 0
2019-03-28 Fixed leds and double click function
    [CAN_Logger_with_Autobaud_and_Requests.ino]
2019-04-04 Removed Silent Pin to ensure accurate transmission of data.
2019-04-08 Change request message ID to BAM, fix ISO request skipping first message
    [CAN_Logger_with_Autobaud_and_Requests.ino]
2019-04-08 CAN2 switch
    Pull it high to activate can2
2019-04-08 Silent pin
    Set silent pin for CAN2 low to enable sending request message
